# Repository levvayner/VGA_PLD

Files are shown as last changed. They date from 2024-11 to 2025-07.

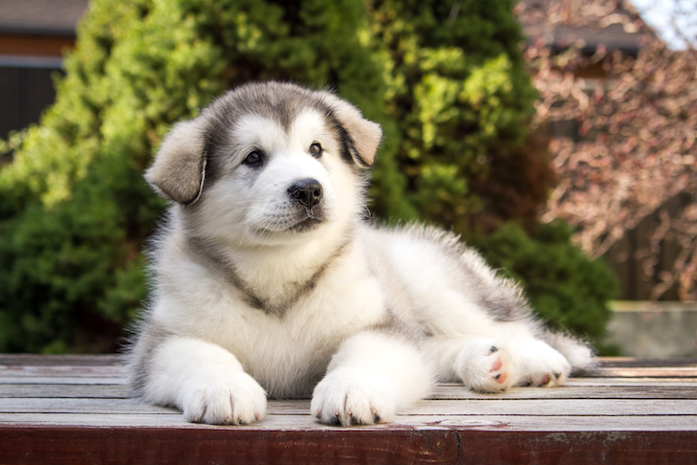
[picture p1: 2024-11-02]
BitmapMapper/puppy_original.png

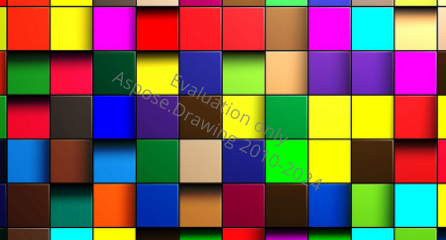
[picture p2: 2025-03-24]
BitmapMapper/blocksResized.bmp

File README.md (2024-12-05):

# VGA Video Card
This project uses TTL components and 2 GALs to create a video card.
There are several parts to the entire development system to aid in development and troubleshooting. Another repository for code that is used on the Arduino Due can be found at https://github.com/levvayner/SRAM-Console

## Parts
 - Hardware Design files in KiCad
 - 2 projects for progamming GAL22V10C PLDs
 - Application used to refine and upload images to the Arduino Due
 - Timing and other documentation
 - Firmware for the Arduino Due to host the video card (https://github.com/levvayner/SRAM-Console)

 ## Getting Started

 ### Prerequisites
 #### Schematics
KiCad software - available for free @ https://www.kicad.org/
 #### Programmable Logic Devices
This can be done with the official Atmel software (https://www.microchip.com/en-us/products/fpgas-and-plds/spld-cplds/pld-design-resources) on windows and using their programmer. 
An alternative approach is to use a cheap progammer like the **TL866+** and using Microsoft Code with the **VS Cupl** extension.
 -http://www.xgecu.com/en/TL866_main.html
-https://marketplace.visualstudio.com/items?itemName=VaynerSystems.VS-Cupl

If choosing the former, follow Atmel's instructions using the included .pld files. If chosing the latter, you can open the workspace and you will see both projects. You can build and deploy the projects right from Code!

You will need to download the Atmel Wincupl progam either way. If you chose to use VS code, you will also need to download and install minipro. More instructions about requirements can be found in the VS Cupl repo https://github.com/levvayner/ATF15xx-cupl

#### Microcontroller
The project uses an Arduino Due uC. The device is low cost, offers a great deal of pins, and has a low price point.

Another device like the Arduino MEGA may suffice. 
Install Microsoft's Code and install the Platform IO extension.
The project can be found here: https://github.com/levvayner/SRAM-Console

## Building the hardware

You can use a breadboard and follow the schematic to build the circuit. First the clock and counters are wired. Then the PLDs are wired to execute combinatory logic to determine timing signals like V-SYNC, H-SYNC, and others like when the screen is not displaying, marking it safe to write to RAM.

The components used in the schematic are available in the KiCad project's output folder.
Currently they are

| Component | Source |
| --- | --- |
| Arduino Due | https://docs.arduino.cc/hardware/due |
| Capactitor (0805) 560 pf  | ebay, mouser, digikey |
| Capacitor Tantalum | ebay, mouser, digikey |
| 2.54mm pins | ebay, mouser, digikey |
| DSUB 15 pin VGA connector | ebay, mouser, digikey |
| USB type A connector | ebay, mouser, digikey |
| Resistors (0805) | ebay, mouser, digikey |
| K6X8008T2B-TF55 | https://www.alldatasheet.com/datasheet-pdf/download/85484/SAMSUNG/K6X8008C2B-TF55.html |
| 74HC245D | ebay, mouser, digikey |
| 74HC161D | ebay, mouser, digikey |
| 74HC32D | ebay, mouser, digikey |
| 74HC08D | ebay, mouser, digikey |
| 74HC00D | ebay, mouser, digikey |
| 74HC14D | ebay, mouser, digikey |
| GAL22V10 | ebay, mouser, digikey |
| 16MHz Full can oscillator | ebay, mouser, digikey |

### GALs
The programmable logic devices are not absolutely required. They can be replaced by inverters and a few logic gates to determine when a counter should trigger a signal (e.g. h-sync at count 603) and use the counter inputs to determine if that number is reached. Several flip flops can be used for storing the state e.g. store v-sync bit at frame 610, clear at 620.
However you may want to change timings or the clock speed to accomplish a different resolution or pixel density. It is much easier to reprogram the GALS to change timing than to re-wire these logic gates. If you have finalized your design, chaning to logic gates and flip flops is recommended. Even better you can use a magnitude comperator instead of a collection of logic gates.

>To progam the gals, you may need to erase the chip. Some chips come locked, and the programmer software from XGECU has an option to clear it. If your changes don't seem to take affect after programming, use their software to make sure the chip is not locked.

There are two projects included. One is used for the horizontal timing, the other for vertical.

>*There is **VGA_SINGLE_PLD** project that can use an **ATF1504AS** instead of these two, but it has not been verified.*

### Arduino 
The project [VGA Controller](https://github.com/levvayner/SRAM-Console) can be used to interface with and develop the video card further. It has functionality to connect to the controller from its serial port, or connect a PS/2 keyboard (experimental) 

## Roadmap
- Add PS/2 mouse support
- Add second SRAM chip to expand data bus to 16 bit
- Add second SRAM chip to round-robin 2 chips between controller and video output, allowing for controller to read/write to SRAM without interfering with the VGA rendering process.

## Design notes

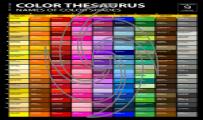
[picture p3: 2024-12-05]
BitmapMapper/colorsResized.bmp

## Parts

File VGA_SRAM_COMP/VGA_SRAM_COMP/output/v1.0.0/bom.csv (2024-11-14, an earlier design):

Reference | Value | Datasheet | Footprint | Qty | DNP
A1 | Arduino_Due_Shield | https://docs.arduino.cc/hardware/due | arduino-library:Arduino_Due_Shield | 1
C1,C2,C3,C4,C5,C7,C8 | 560pf | ~ | Capacitor_SMD:C_0805_2012Metric | 7
C6,C9 | C_Small | ~ | Capacitor_Tantalum_SMD:CP_EIA-7132-28_AVX-C | 2
J1 | DIAG | ~ | Connector_PinSocket_2.54mm:PinSocket_2x04_P2.54mm_Vertical | 1
J2 | PWR AUX | ~ | Connector_PinSocket_2.54mm:PinSocket_2x02_P2.54mm_Vertical | 1
J3 | DE15_Receptacle_HighDensity | ~ | Connector_Dsub:DSUB-15-HD_Female_Horizontal_P2.29x1.98mm_EdgePinOffset8.35mm_Housed_MountingHolesOffset10.89mm | 1
J5 | USB_A | ~ | Connector_USB:USB_A_Molex_67643_Horizontal | 1
R1,R4,R7 | R470 | ~ | Resistor_SMD:R_0805_2012Metric | 3
R2,R5,R8 | R900 | ~ | Resistor_SMD:R_0805_2012Metric | 3
R3,R6 | R1.5K | ~ | Resistor_SMD:R_0805_2012Metric | 2
R10 | R10K | ~ | Resistor_SMD:R_0805_2012Metric | 1
R11,R12 | R100 | ~ | Resistor_SMD:R_0805_2012Metric | 2
U1 | K6X8008T2B-TF55 | https://www.alldatasheet.com/datasheet-pdf/download/85484/SAMSUNG/K6X8008C2B-TF55.html | Package_SO:TSOP-II-44_10.16x18.41mm_P0.8mm | 1
U2,U11,U12,U13,U14,U18,U20 | 74HC245 | http://www.ti.com/lit/gpn/sn74HC245 | Package_SO:SOP-20_7.5x12.8mm_P1.27mm | 7
U3,U4,U5,U6,U7,U10 | 74LS161 | http://www.ti.com/lit/gpn/sn74LS161 | Package_SO:SO-16_3.9x9.9mm_P1.27mm | 6
U8,U9 | GAL22V10 |  | Package_DIP:DIP-24_W10.16mm_Socket | 2
U15 | 74LS32 | http://www.ti.com/lit/gpn/sn74LS32 | Package_SO:SO-14_3.9x8.65mm_P1.27mm | 1
U16 | 74LS08 | http://www.ti.com/lit/gpn/sn74LS08 | Package_SO:SO-14_3.9x8.65mm_P1.27mm | 1
U17 | 74HC00 | http://www.ti.com/lit/gpn/sn74hc00 | Package_SO:SO-14_3.9x8.65mm_P1.27mm | 1
U19 | 74HC14 | http://www.ti.com/lit/gpn/sn74HC14 | Package_SO:SO-14_3.9x8.65mm_P1.27mm | 1
X1 | TCXO-14 | http://www.golledge.com/pdf/products/tcxos/gtxos14.pdf | Oscillator:Oscillator_DIP-14 | 1

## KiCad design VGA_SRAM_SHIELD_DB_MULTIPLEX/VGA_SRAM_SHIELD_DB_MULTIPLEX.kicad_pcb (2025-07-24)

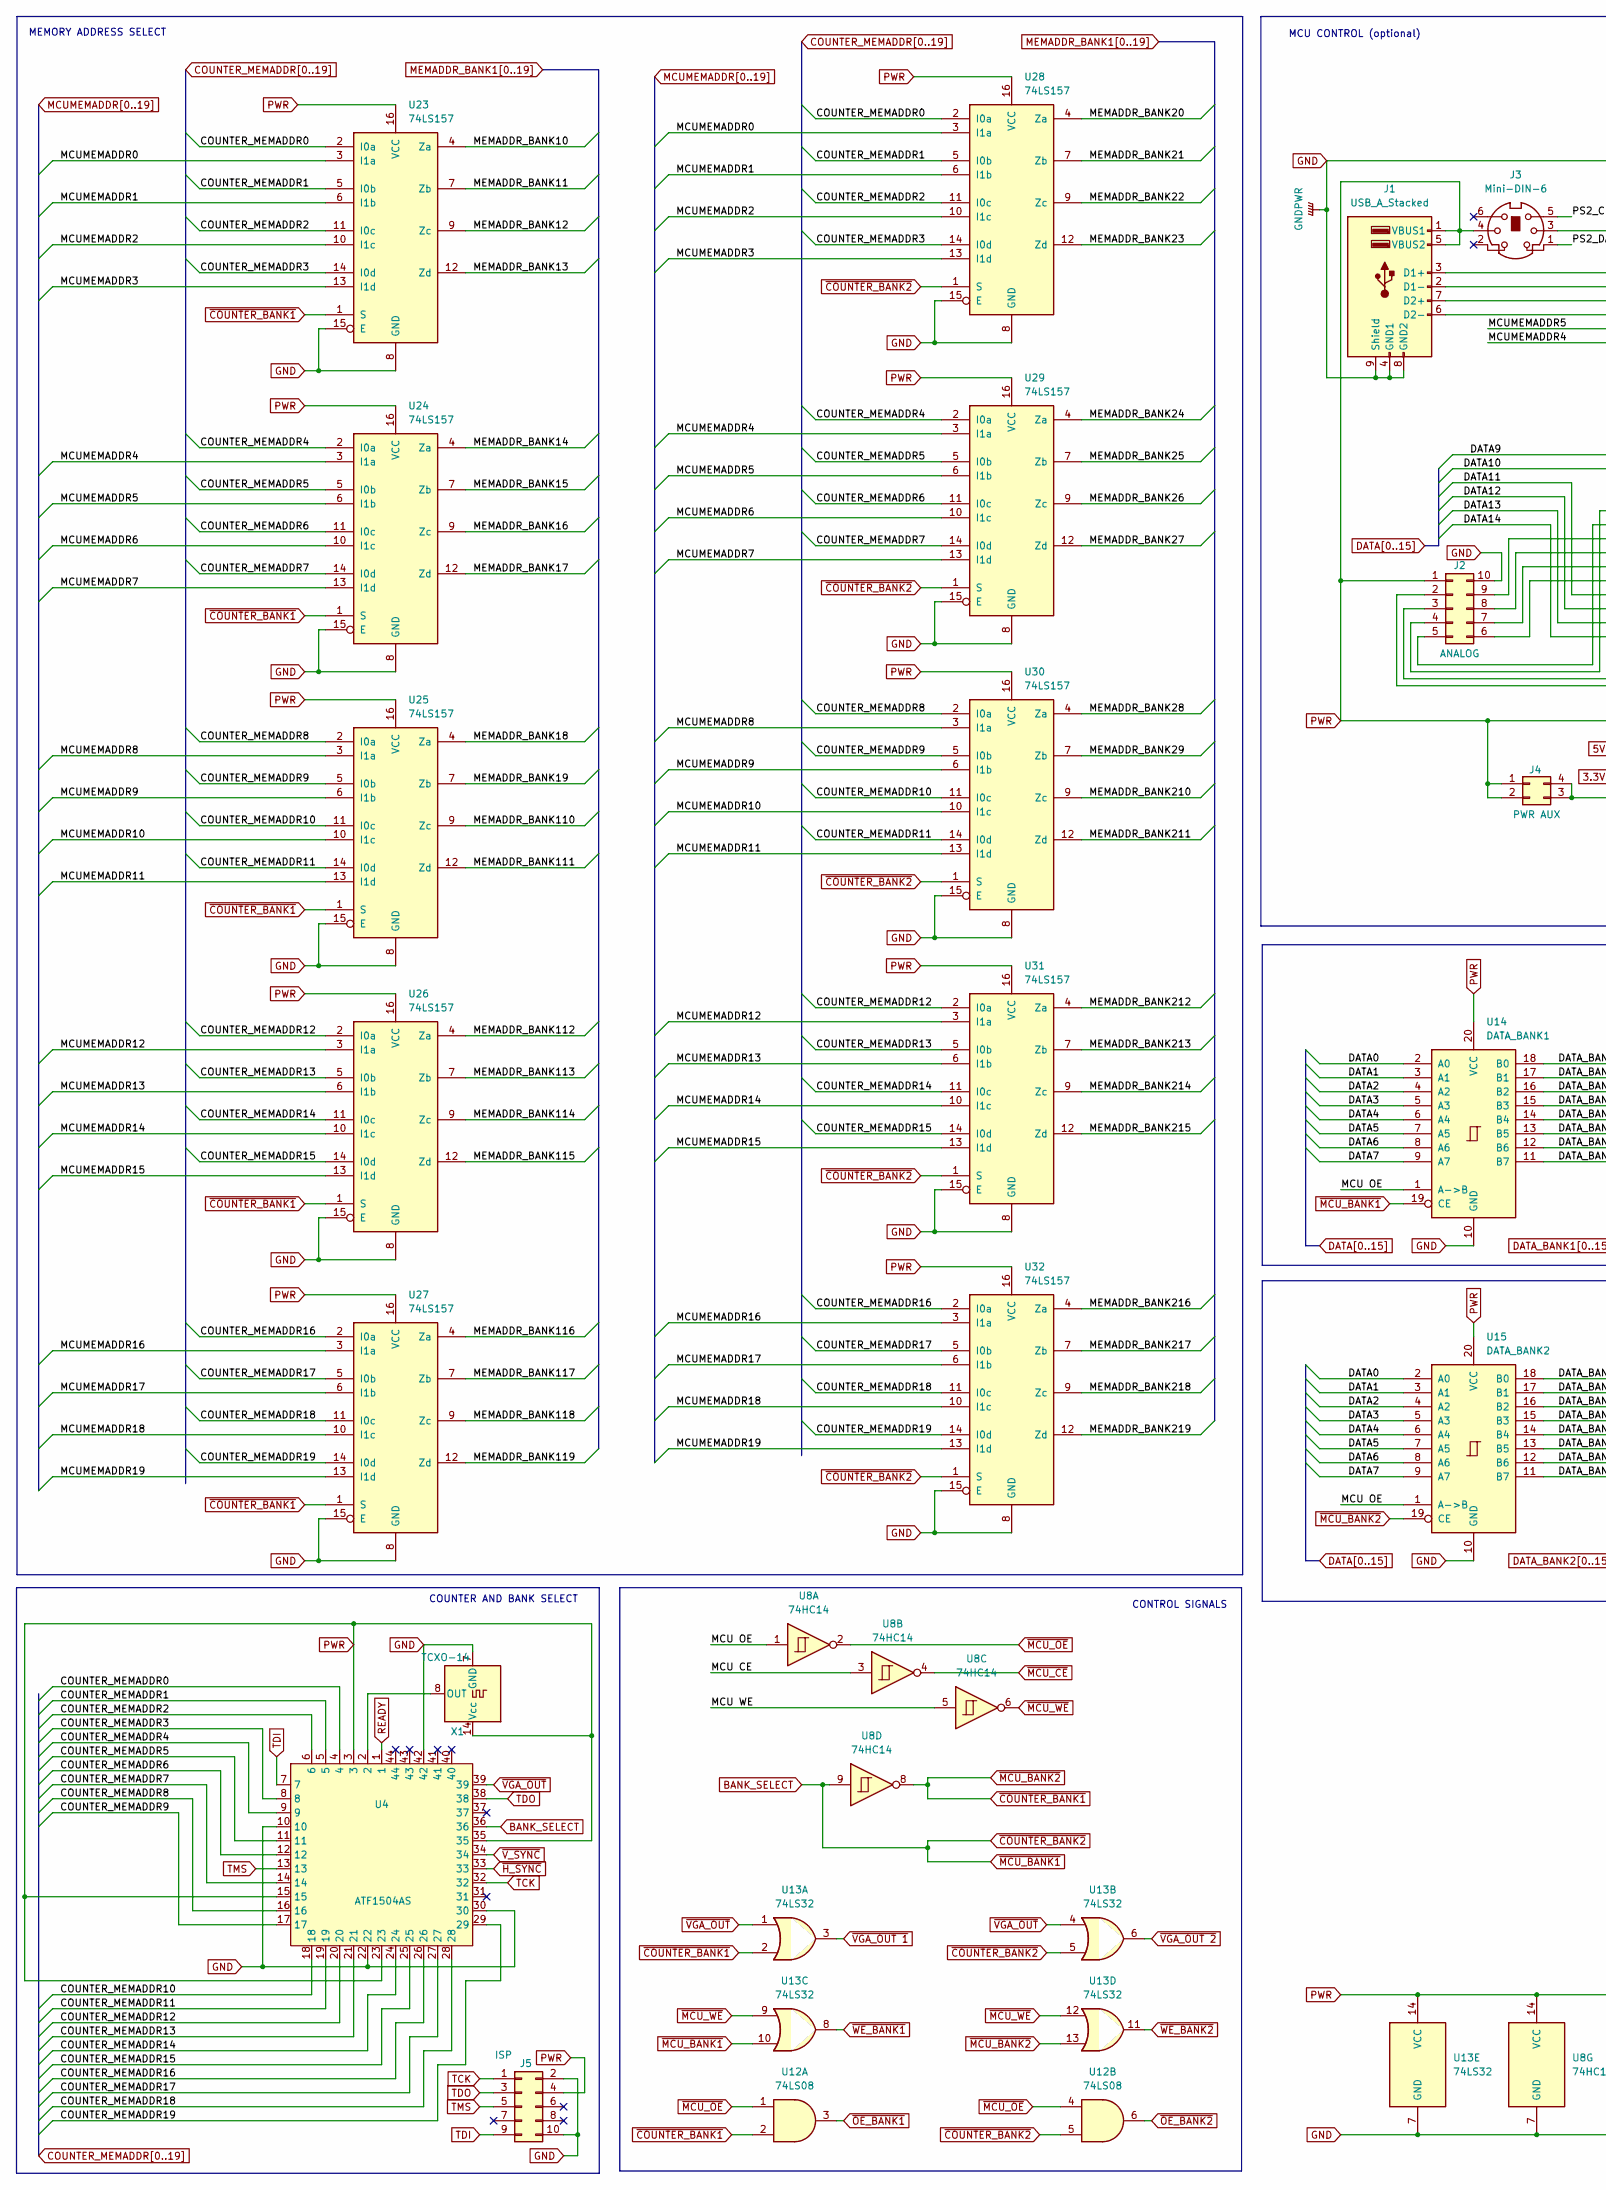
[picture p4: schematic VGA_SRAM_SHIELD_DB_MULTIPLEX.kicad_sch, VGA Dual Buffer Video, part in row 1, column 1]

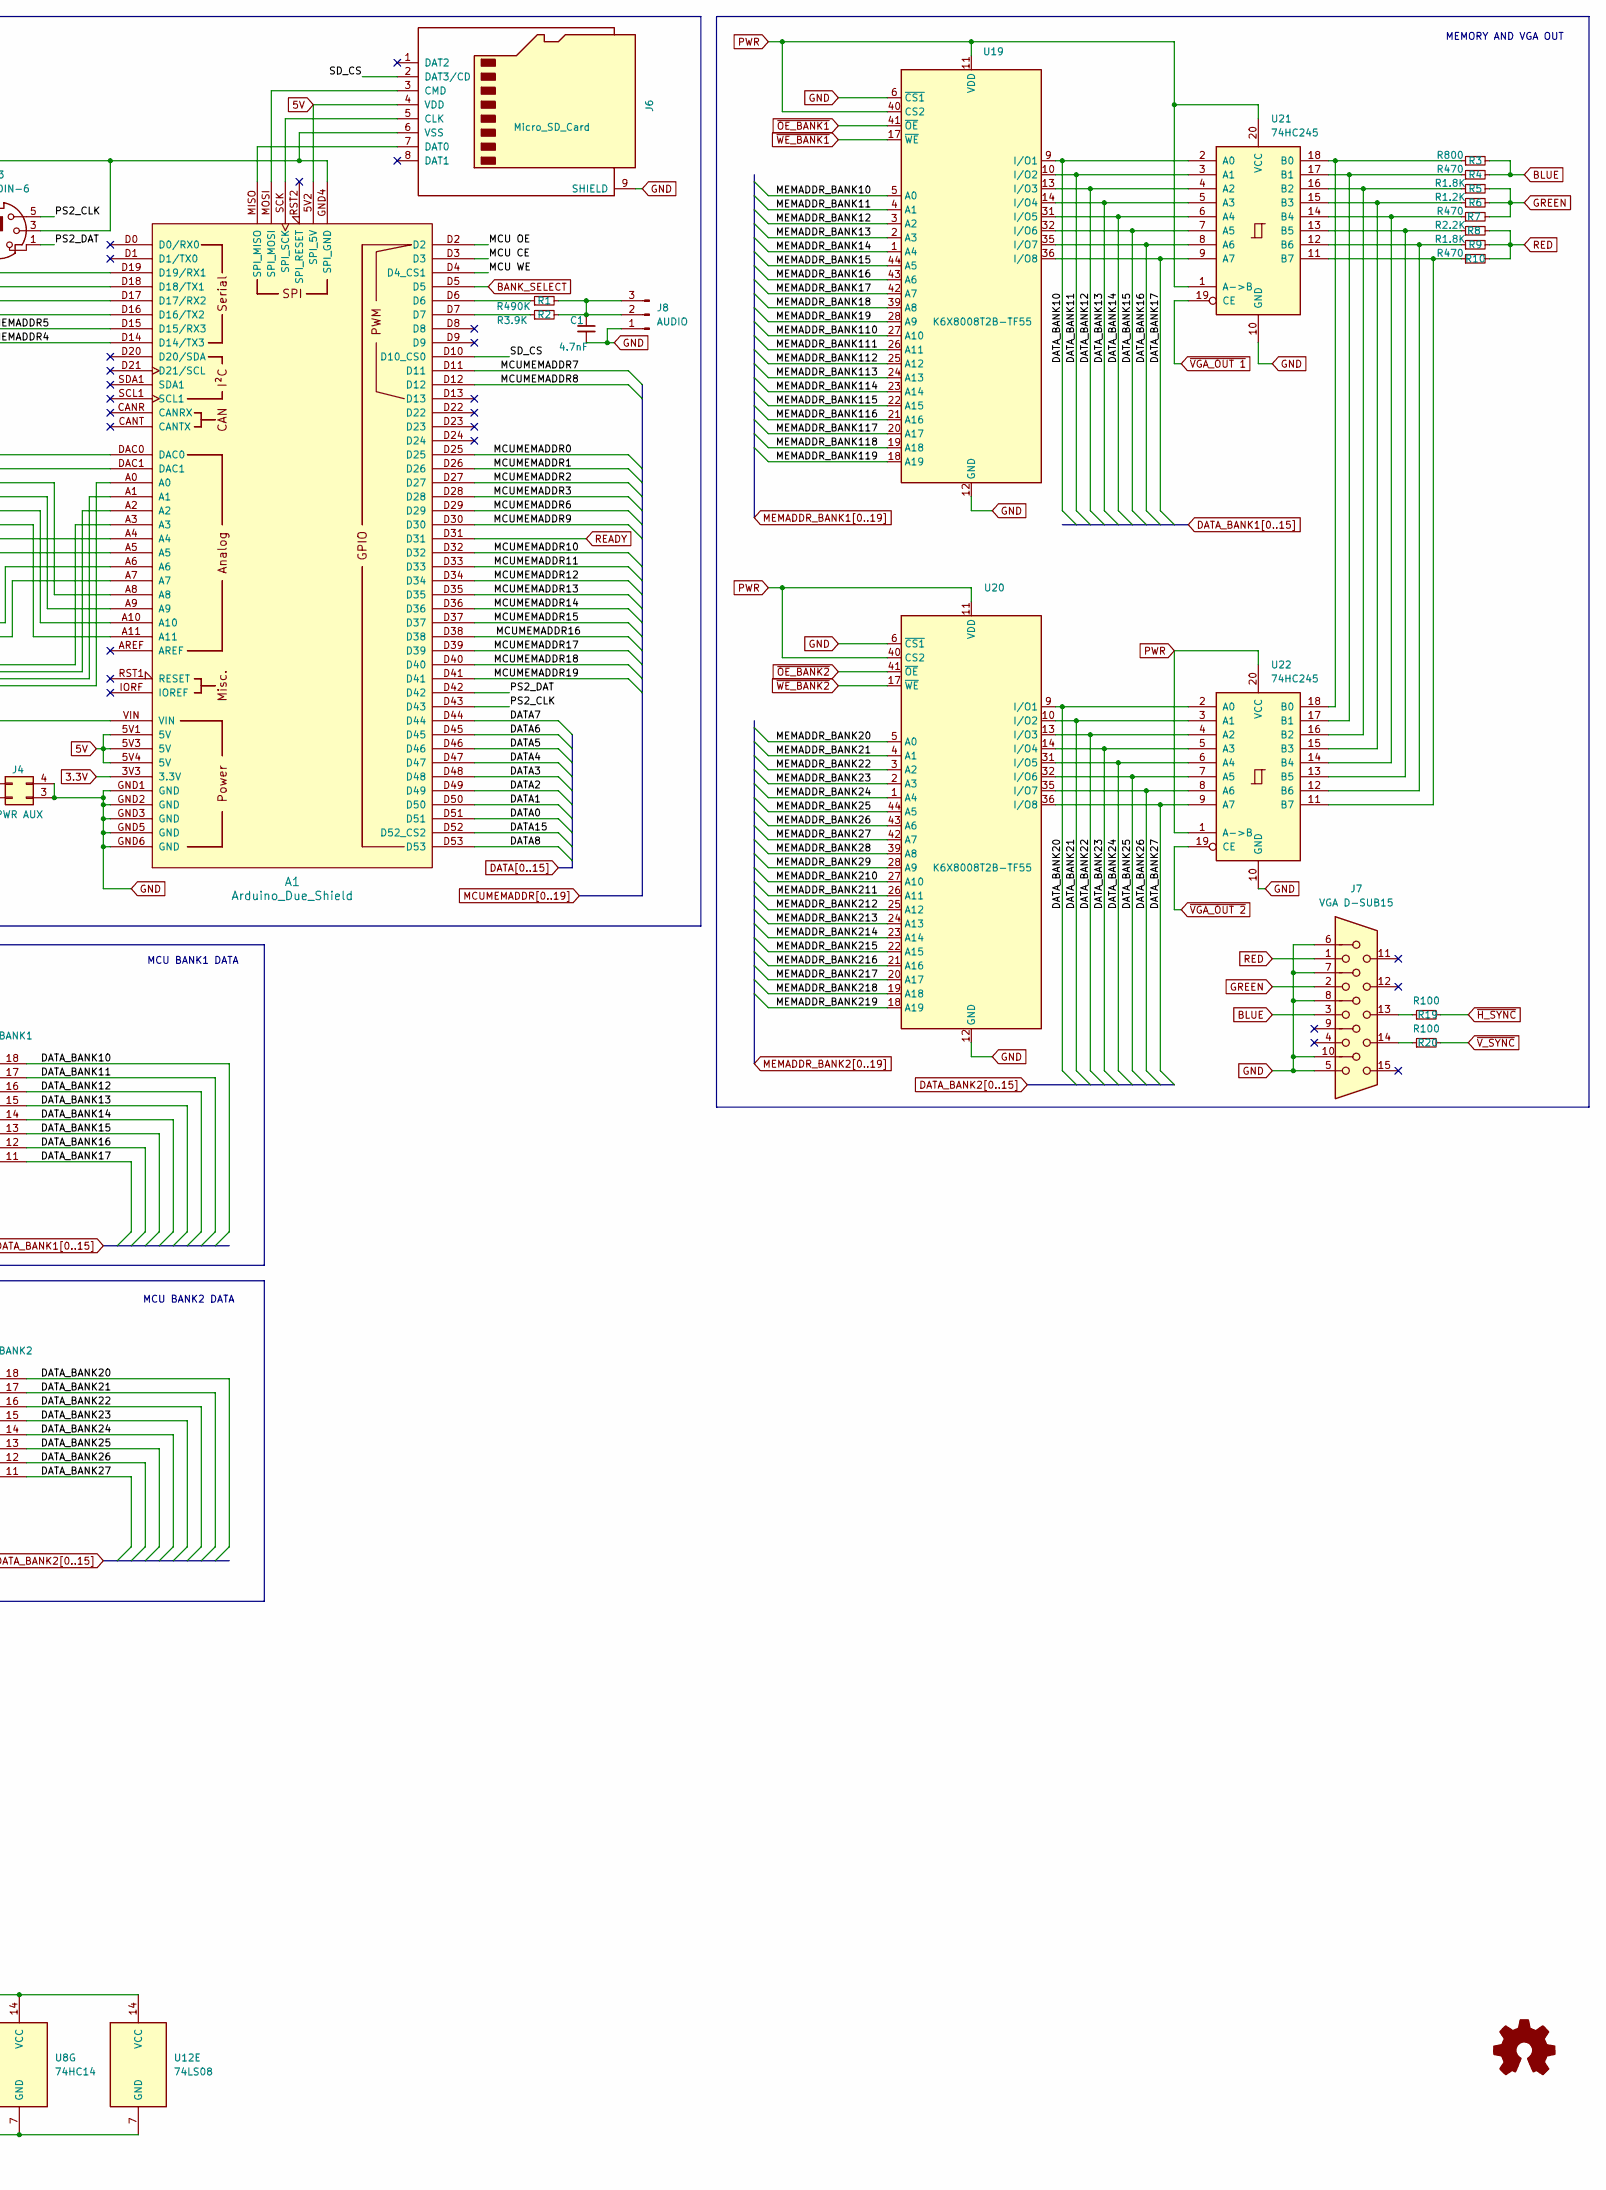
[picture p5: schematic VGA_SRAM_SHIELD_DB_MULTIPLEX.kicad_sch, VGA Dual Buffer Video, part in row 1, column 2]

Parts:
A1: Arduino_Due_Shield
C1: 4.7nF; C_0805_2012Metric
J1: USB_A_Stacked; USB_A_CUI_UJ2-ADH-TH_Horizontal_Stacked
J2: ANALOG; PinSocket_2x05_P2.54mm_Vertical
J3: Mini-DIN-6; mini-DIN 6
J4: PWR AUX; PinSocket_2x02_P2.54mm_Vertical
J5: ISP; PinSocket_2x05_P2.54mm_Vertical
J6: Micro_SD_Card; J_SD_Card-micro_socket_A
J7: VGA D-SUB15; DSUB-15-HD_Female_Horizontal_P2.29x1.98mm_EdgePinOffset8.35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
J8: AUDIO; PinSocket_1x03_P2.54mm_Vertical
R1: R490K; R_0805_2012Metric
R2: R3.9K; R_0805_2012Metric
R3: R800; R_0805_2012Metric
R4, R7, R10: R470; R_0805_2012Metric
R5, R9: R1.8K; R_0805_2012Metric
R6: R1.2K; R_0805_2012Metric
R8: R2.2K; R_0805_2012Metric
R19, R20: R100; R_0805_2012Metric
U4: ATF1504AS; PLCC-44_THT-Socket
U8: 74HC14; SO-14_3.9x8.65mm_P1.27mm
U12: 74LS08; SO-14_3.9x8.65mm_P1.27mm
U13: 74LS32; SO-14_3.9x8.65mm_P1.27mm
U14: DATA_BANK1; SOP-20_7.5x12.8mm_P1.27mm
U15: DATA_BANK2; SOP-20_7.5x12.8mm_P1.27mm
U19, U20: K6X8008T2B-TF55; TSOP-II-44_10.16x18.41mm_P0.8mm
U21, U22: 74HC245; SOP-20_7.5x12.8mm_P1.27mm
U23, U24, U25, U26, U27, U28, U29, U30, U31, U32: 74LS157; SOP-16_3.9x9.9mm_P1.27mm
X1: TCXO-14; Oscillator_DIP-14

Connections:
3.3V: A1.3V3 (3.3V)
5V: A1.5V1 (5V), A1.5V2 (SPI_5V), A1.5V3 (5V), A1.5V4 (5V), J6.4 (VDD)
/MCU CE: A1.D3, U8.3
/MCU OE: A1.D2, U8.1, U14.1 (A->B), U15.1 (A->B)
/MCU WE: A1.D4 (D4_CS1), U8.5
/PS2_CLK: A1.D43, J3.5
/PS2_DAT: A1.D42, J3.1
/SD_CS: A1.D10 (D10_CS0), J6.2 (DAT3/CD)
BANK_SELECT: A1.D5, U4.36, U8.9, U12.5, U13.5, U13.10, U14.19 (CE), U28.1 (S), U29.1 (S), U30.1 (S), U31.1 (S), U32.1 (S)
BLUE: J7.3, R3.2, R4.2
COUNTER_MEMADDR0: U4.4, U23.2 (I0a), U28.2 (I0a)
COUNTER_MEMADDR1: U4.5, U23.5 (I0b), U28.5 (I0b)
COUNTER_MEMADDR2: U4.6, U23.11 (I0c), U28.11 (I0c)
COUNTER_MEMADDR3: U4.8, U23.14 (I0d), U28.14 (I0d)
COUNTER_MEMADDR4: U4.9, U24.2 (I0a), U29.2 (I0a)
COUNTER_MEMADDR5: U4.11, U24.5 (I0b), U29.5 (I0b)
COUNTER_MEMADDR6: U4.12, U24.11 (I0c), U29.11 (I0c)
COUNTER_MEMADDR7: U4.14, U24.14 (I0d), U29.14 (I0d)
COUNTER_MEMADDR8: U4.16, U25.2 (I0a), U30.2 (I0a)
COUNTER_MEMADDR9: U4.17, U25.5 (I0b), U30.5 (I0b)
COUNTER_MEMADDR10: U4.18, U25.11 (I0c), U30.11 (I0c)
COUNTER_MEMADDR11: U4.19, U25.14 (I0d), U30.14 (I0d)
COUNTER_MEMADDR12: U4.20, U26.2 (I0a), U31.2 (I0a)
COUNTER_MEMADDR13: U4.21, U26.5 (I0b), U31.5 (I0b)
COUNTER_MEMADDR14: U4.24, U26.11 (I0c), U31.11 (I0c)
COUNTER_MEMADDR15: U4.25, U26.14 (I0d), U31.14 (I0d)
COUNTER_MEMADDR16: U4.26, U27.2 (I0a), U32.2 (I0a)
COUNTER_MEMADDR17: U4.27, U27.5 (I0b), U32.5 (I0b)
COUNTER_MEMADDR18: U4.28, U27.11 (I0c), U32.11 (I0c)
COUNTER_MEMADDR19: U4.29, U27.14 (I0d), U32.14 (I0d)
DATA0: A1.D51, U14.2 (A0), U15.2 (A0)
DATA1: A1.D50, U14.3 (A1), U15.3 (A1)
DATA2: A1.D49, U14.4 (A2), U15.4 (A2)
DATA3: A1.D48, U14.5 (A3), U15.5 (A3)
DATA4: A1.D47, U14.6 (A4), U15.6 (A4)
DATA5: A1.D46, U14.7 (A5), U15.7 (A5)
DATA6: A1.D45, U14.8 (A6), U15.8 (A6)
DATA7: A1.D44, U14.9 (A7), U15.9 (A7)
DATA8: A1.D53
DATA9: A1.DAC0
DATA10: A1.DAC1
DATA11: A1.A8
DATA12: A1.A9
DATA13: A1.A10
DATA14: A1.A11
DATA15: A1.D52 (D52_CS2)
DATA_BANK10: U14.18 (B0), U19.9 (I/O1), U21.2 (A0)
DATA_BANK11: U14.17 (B1), U19.10 (I/O2), U21.3 (A1)
DATA_BANK12: U14.16 (B2), U19.13 (I/O3), U21.4 (A2)
DATA_BANK13: U14.15 (B3), U19.14 (I/O4), U21.5 (A3)
DATA_BANK14: U14.14 (B4), U19.31 (I/O5), U21.6 (A4)
DATA_BANK15: U14.13 (B5), U19.32 (I/O6), U21.7 (A5)
DATA_BANK16: U14.12 (B6), U19.35 (I/O7), U21.8 (A6)
DATA_BANK17: U14.11 (B7), U19.36 (I/O8), U21.9 (A7)
DATA_BANK20: U15.18 (B0), U20.9 (I/O1), U22.2 (A0)
DATA_BANK21: U15.17 (B1), U20.10 (I/O2), U22.3 (A1)
DATA_BANK22: U15.16 (B2), U20.13 (I/O3), U22.4 (A2)
DATA_BANK23: U15.15 (B3), U20.14 (I/O4), U22.5 (A3)
DATA_BANK24: U15.14 (B4), U20.31 (I/O5), U22.6 (A4)
DATA_BANK25: U15.13 (B5), U20.32 (I/O6), U22.7 (A5)
DATA_BANK26: U15.12 (B6), U20.35 (I/O7), U22.8 (A6)
DATA_BANK27: U15.11 (B7), U20.36 (I/O8), U22.9 (A7)
GND: A1.GND1 (GND), A1.GND2 (GND), A1.GND3 (GND), A1.GND4 (SPI_GND), A1.GND5 (GND), A1.GND6 (GND), C1.2, J1.4 (GND1), J1.8 (GND2), J1.9 (Shield), J2.10, J3.3, J4.3, J4.4, J5.2, J5.10, J6.6 (VSS), J6.9 (SHIELD), J7.5, J7.6, J7.7, J7.8, J7.10, J8.1, U4.10, U4.22, U4.30, U4.42, U8.7 (GND), U12.7 (GND), U13.7 (GND), U14.10 (GND), U15.10 (GND), U19.6 (~CS1), U19.12 (GND), U19.34 (GND), U20.6 (~CS1), U20.12 (GND), U20.34 (GND), U21.10 (GND), U22.10 (GND), U23.8 (GND), U23.15 (E), U24.8 (GND), U24.15 (E), U25.8 (GND), U25.15 (E), U26.8 (GND), U26.15 (E), U27.8 (GND), U27.15 (E), U28.8 (GND), U28.15 (E), U29.8 (GND), U29.15 (E), U30.8 (GND), U30.15 (E), U31.8 (GND), U31.15 (E), U32.8 (GND), U32.15 (E), X1.7 (GND)
GREEN: J7.2, R5.2, R6.2, R7.2
MCUMEMADDR0: A1.D25, U23.3 (I1a), U28.3 (I1a)
MCUMEMADDR1: A1.D26, U23.6 (I1b), U28.6 (I1b)
MCUMEMADDR2: A1.D27, U23.10 (I1c), U28.10 (I1c)
MCUMEMADDR3: A1.D28, U23.13 (I1d), U28.13 (I1d)
MCUMEMADDR4: A1.D14 (D14/TX3), U24.3 (I1a), U29.3 (I1a)
MCUMEMADDR5: A1.D15 (D15/RX3), U24.6 (I1b), U29.6 (I1b)
MCUMEMADDR6: A1.D29, U24.10 (I1c), U29.10 (I1c)
MCUMEMADDR7: A1.D11, U24.13 (I1d), U29.13 (I1d)
MCUMEMADDR8: A1.D12, U25.3 (I1a), U30.3 (I1a)
MCUMEMADDR9: A1.D30, U25.6 (I1b), U30.6 (I1b)
MCUMEMADDR10: A1.D32, U25.10 (I1c), U30.10 (I1c)
MCUMEMADDR11: A1.D33, U25.13 (I1d), U30.13 (I1d)
MCUMEMADDR12: A1.D34, U26.3 (I1a), U31.3 (I1a)
MCUMEMADDR13: A1.D35, U26.6 (I1b), U31.6 (I1b)
MCUMEMADDR14: A1.D36, U26.10 (I1c), U31.10 (I1c)
MCUMEMADDR15: A1.D37, U26.13 (I1d), U31.13 (I1d)
MCUMEMADDR16: A1.D38, U27.3 (I1a), U32.3 (I1a)
MCUMEMADDR17: A1.D39, U27.6 (I1b), U32.6 (I1b)
MCUMEMADDR18: A1.D40, U27.10 (I1c), U32.10 (I1c)
MCUMEMADDR19: A1.D41, U27.13 (I1d), U32.13 (I1d)
MEMADDR_BANK10: U19.5 (A0), U23.4 (Za)
MEMADDR_BANK11: U19.4 (A1), U23.7 (Zb)
MEMADDR_BANK12: U19.3 (A2), U23.9 (Zc)
MEMADDR_BANK13: U19.2 (A3), U23.12 (Zd)
MEMADDR_BANK14: U19.1 (A4), U24.4 (Za)
MEMADDR_BANK15: U19.44 (A5), U24.7 (Zb)
MEMADDR_BANK16: U19.43 (A6), U24.9 (Zc)
MEMADDR_BANK17: U19.42 (A7), U24.12 (Zd)
MEMADDR_BANK18: U19.39 (A8), U25.4 (Za)
MEMADDR_BANK19: U19.28 (A9), U25.7 (Zb)
MEMADDR_BANK20: U20.5 (A0), U28.4 (Za)
MEMADDR_BANK21: U20.4 (A1), U28.7 (Zb)
MEMADDR_BANK22: U20.3 (A2), U28.9 (Zc)
MEMADDR_BANK23: U20.2 (A3), U28.12 (Zd)
MEMADDR_BANK24: U20.1 (A4), U29.4 (Za)
MEMADDR_BANK25: U20.44 (A5), U29.7 (Zb)
MEMADDR_BANK26: U20.43 (A6), U29.9 (Zc)
MEMADDR_BANK27: U20.42 (A7), U29.12 (Zd)
MEMADDR_BANK28: U20.39 (A8), U30.4 (Za)
MEMADDR_BANK29: U20.28 (A9), U30.7 (Zb)
MEMADDR_BANK110: U19.27 (A10), U25.9 (Zc)
MEMADDR_BANK111: U19.26 (A11), U25.12 (Zd)
MEMADDR_BANK112: U19.25 (A12), U26.4 (Za)
MEMADDR_BANK113: U19.24 (A13), U26.7 (Zb)
MEMADDR_BANK114: U19.23 (A14), U26.9 (Zc)
MEMADDR_BANK115: U19.22 (A15), U26.12 (Zd)
MEMADDR_BANK116: U19.21 (A16), U27.4 (Za)
MEMADDR_BANK117: U19.20 (A17), U27.7 (Zb)
MEMADDR_BANK118: U19.19 (A18), U27.9 (Zc)
MEMADDR_BANK119: U19.18 (A19), U27.12 (Zd)
MEMADDR_BANK210: U20.27 (A10), U30.9 (Zc)
MEMADDR_BANK211: U20.26 (A11), U30.12 (Zd)
MEMADDR_BANK212: U20.25 (A12), U31.4 (Za)
MEMADDR_BANK213: U20.24 (A13), U31.7 (Zb)
MEMADDR_BANK214: U20.23 (A14), U31.9 (Zc)
MEMADDR_BANK215: U20.22 (A15), U31.12 (Zd)
MEMADDR_BANK216: U20.21 (A16), U32.4 (Za)
MEMADDR_BANK217: U20.20 (A17), U32.7 (Zb)
MEMADDR_BANK218: U20.19 (A18), U32.9 (Zc)
MEMADDR_BANK219: U20.18 (A19), U32.12 (Zd)
unnamed: A1.D16 (D16/TX2), J1.6 (D2-)
unnamed: A1.D17 (D17/RX2), J1.7 (D2+)
unnamed: A1.D18 (D18/TX1), J1.2 (D1-)
unnamed: A1.D19 (D19/RX1), J1.3 (D1+)
unnamed: A1.D6, R1.1
unnamed: A1.D7, R2.1
unnamed: A1.MISO (SPI_MISO), J6.7 (DAT0)
unnamed: A1.MOSI (SPI_MOSI), J6.3 (CMD)
unnamed: A1.SCK (SPI_SCK), J6.5 (CLK)
unnamed: A1.A0, J2.2
unnamed: A1.A1, J2.3
unnamed: A1.A2, J2.4
unnamed: A1.A3, J2.5
unnamed: A1.A7, J2.6
unnamed: A1.A6, J2.7
unnamed: A1.A5, J2.8
unnamed: A1.A4, J2.9
unnamed: J7.13, R19.1
unnamed: J7.14, R20.1
unnamed: C1.1, J8.2, J8.3, R1.2, R2.2
unnamed: R3.1, U21.18 (B0), U22.18 (B0)
unnamed: R4.1, U21.17 (B1), U22.17 (B1)
unnamed: R5.1, U21.16 (B2), U22.16 (B2)
unnamed: R6.1, U21.15 (B3), U22.15 (B3)
unnamed: R7.1, U21.14 (B4), U22.14 (B4)
unnamed: R8.1, U21.13 (B5), U22.13 (B5)
unnamed: R9.1, U21.12 (B6), U22.12 (B6)
unnamed: R10.1, U21.11 (B7), U22.11 (B7)
unnamed: U4.2, X1.8 (OUT)
PWR: A1.VIN, J1.1 (VBUS1), J1.5 (VBUS2), J2.1, J3.4, J4.1, J4.2, J5.4, U4.3, U4.15, U4.23, U4.35, U8.14 (VCC), U12.14 (VCC), U13.14 (VCC), U14.20 (VCC), U15.20 (VCC), U19.11 (VDD), U19.33 (VDD), U19.40 (CS2), U20.11 (VDD), U20.33 (VDD), U20.40 (CS2), U21.1 (A->B), U21.20 (VCC), U22.1 (A->B), U22.20 (VCC), U23.16 (VCC), U24.16 (VCC), U25.16 (VCC), U26.16 (VCC), U27.16 (VCC), U28.16 (VCC), U29.16 (VCC), U30.16 (VCC), U31.16 (VCC), U32.16 (VCC), X1.14 (Vcc)
READY: A1.D31, U4.1
RED: J7.1, R8.2, R9.2, R10.2
TCK: J5.1, U4.32
TDI: J5.9, U4.7
TDO: J5.3, U4.38
TMS: J5.5, U4.13
~COUNTER_BANK1: U8.8, U12.2, U13.2, U13.13, U15.19 (CE), U23.1 (S), U24.1 (S), U25.1 (S), U26.1 (S), U27.1 (S)
~H_SYNC: R19.2, U4.33
~MCU_CE: U8.4
~MCU_OE: U8.2, U12.1, U12.4
~MCU_WE: U8.6, U13.9, U13.12
~OE_BANK1: U12.3, U19.41 (~OE)
~OE_BANK2: U12.6, U20.41 (~OE)
~VGA_OUT 1: U13.3, U21.19 (CE)
~VGA_OUT 2: U13.6, U22.19 (CE)
~VGA_OUT: U4.39, U13.1, U13.4
~V_SYNC: R20.2, U4.34
~WE_BANK1: U13.8, U19.17 (~WE)
~WE_BANK2: U13.11, U20.17 (~WE)

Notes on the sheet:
MEMORY ADDRESS SELECT
MCU BANK1 DATA
MEMORY AND VGA OUT
MCU BANK2 DATA
MCU CONTROL (optional)
COUNTER AND BANK SELECT
CONTROL SIGNALS

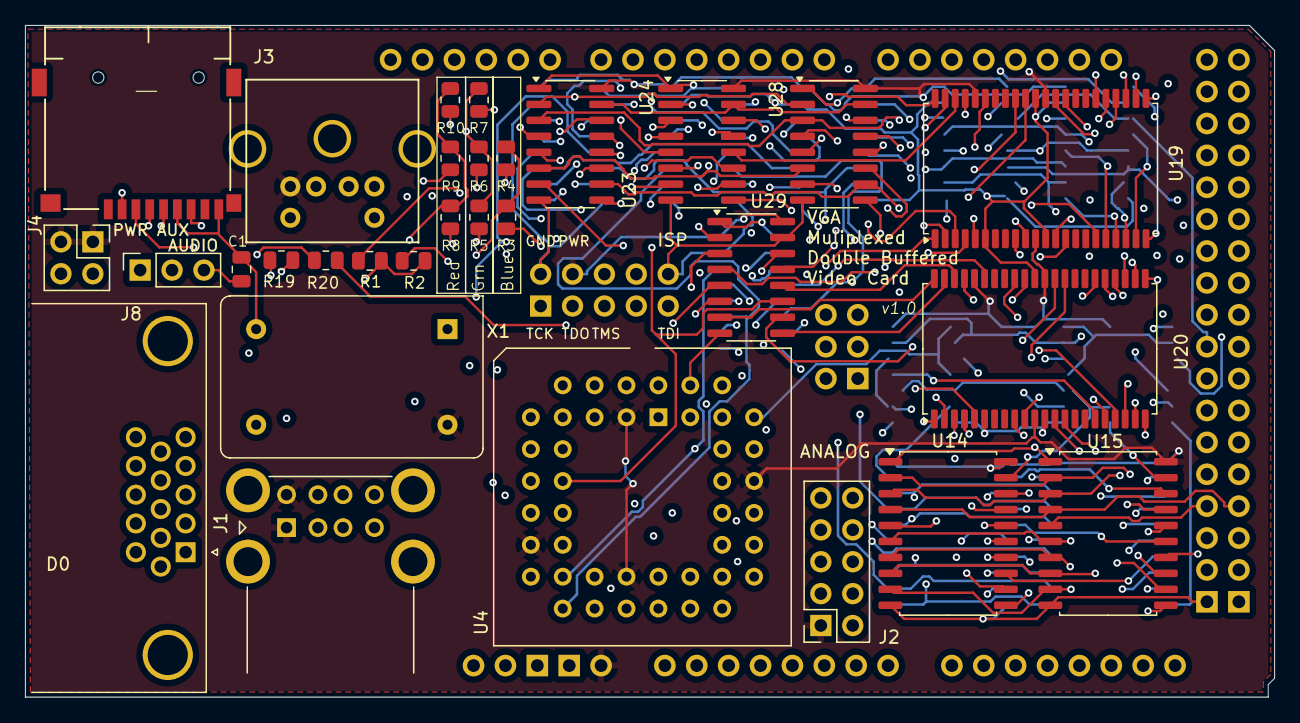
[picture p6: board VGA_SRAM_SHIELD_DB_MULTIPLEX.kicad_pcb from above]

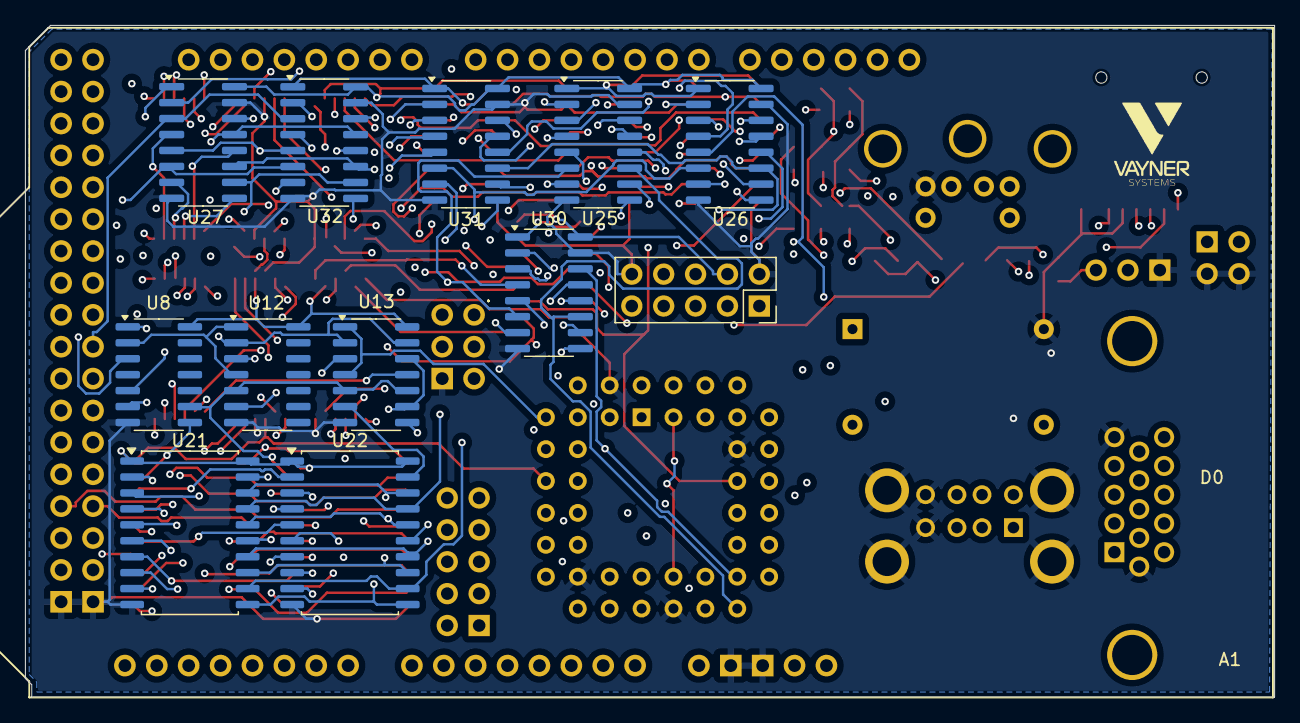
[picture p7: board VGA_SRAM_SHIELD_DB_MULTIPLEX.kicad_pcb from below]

Board: 6 copper layers, 99.5 x 53.5 mm, 43 parts (12 on the bottom side), 163 nets.

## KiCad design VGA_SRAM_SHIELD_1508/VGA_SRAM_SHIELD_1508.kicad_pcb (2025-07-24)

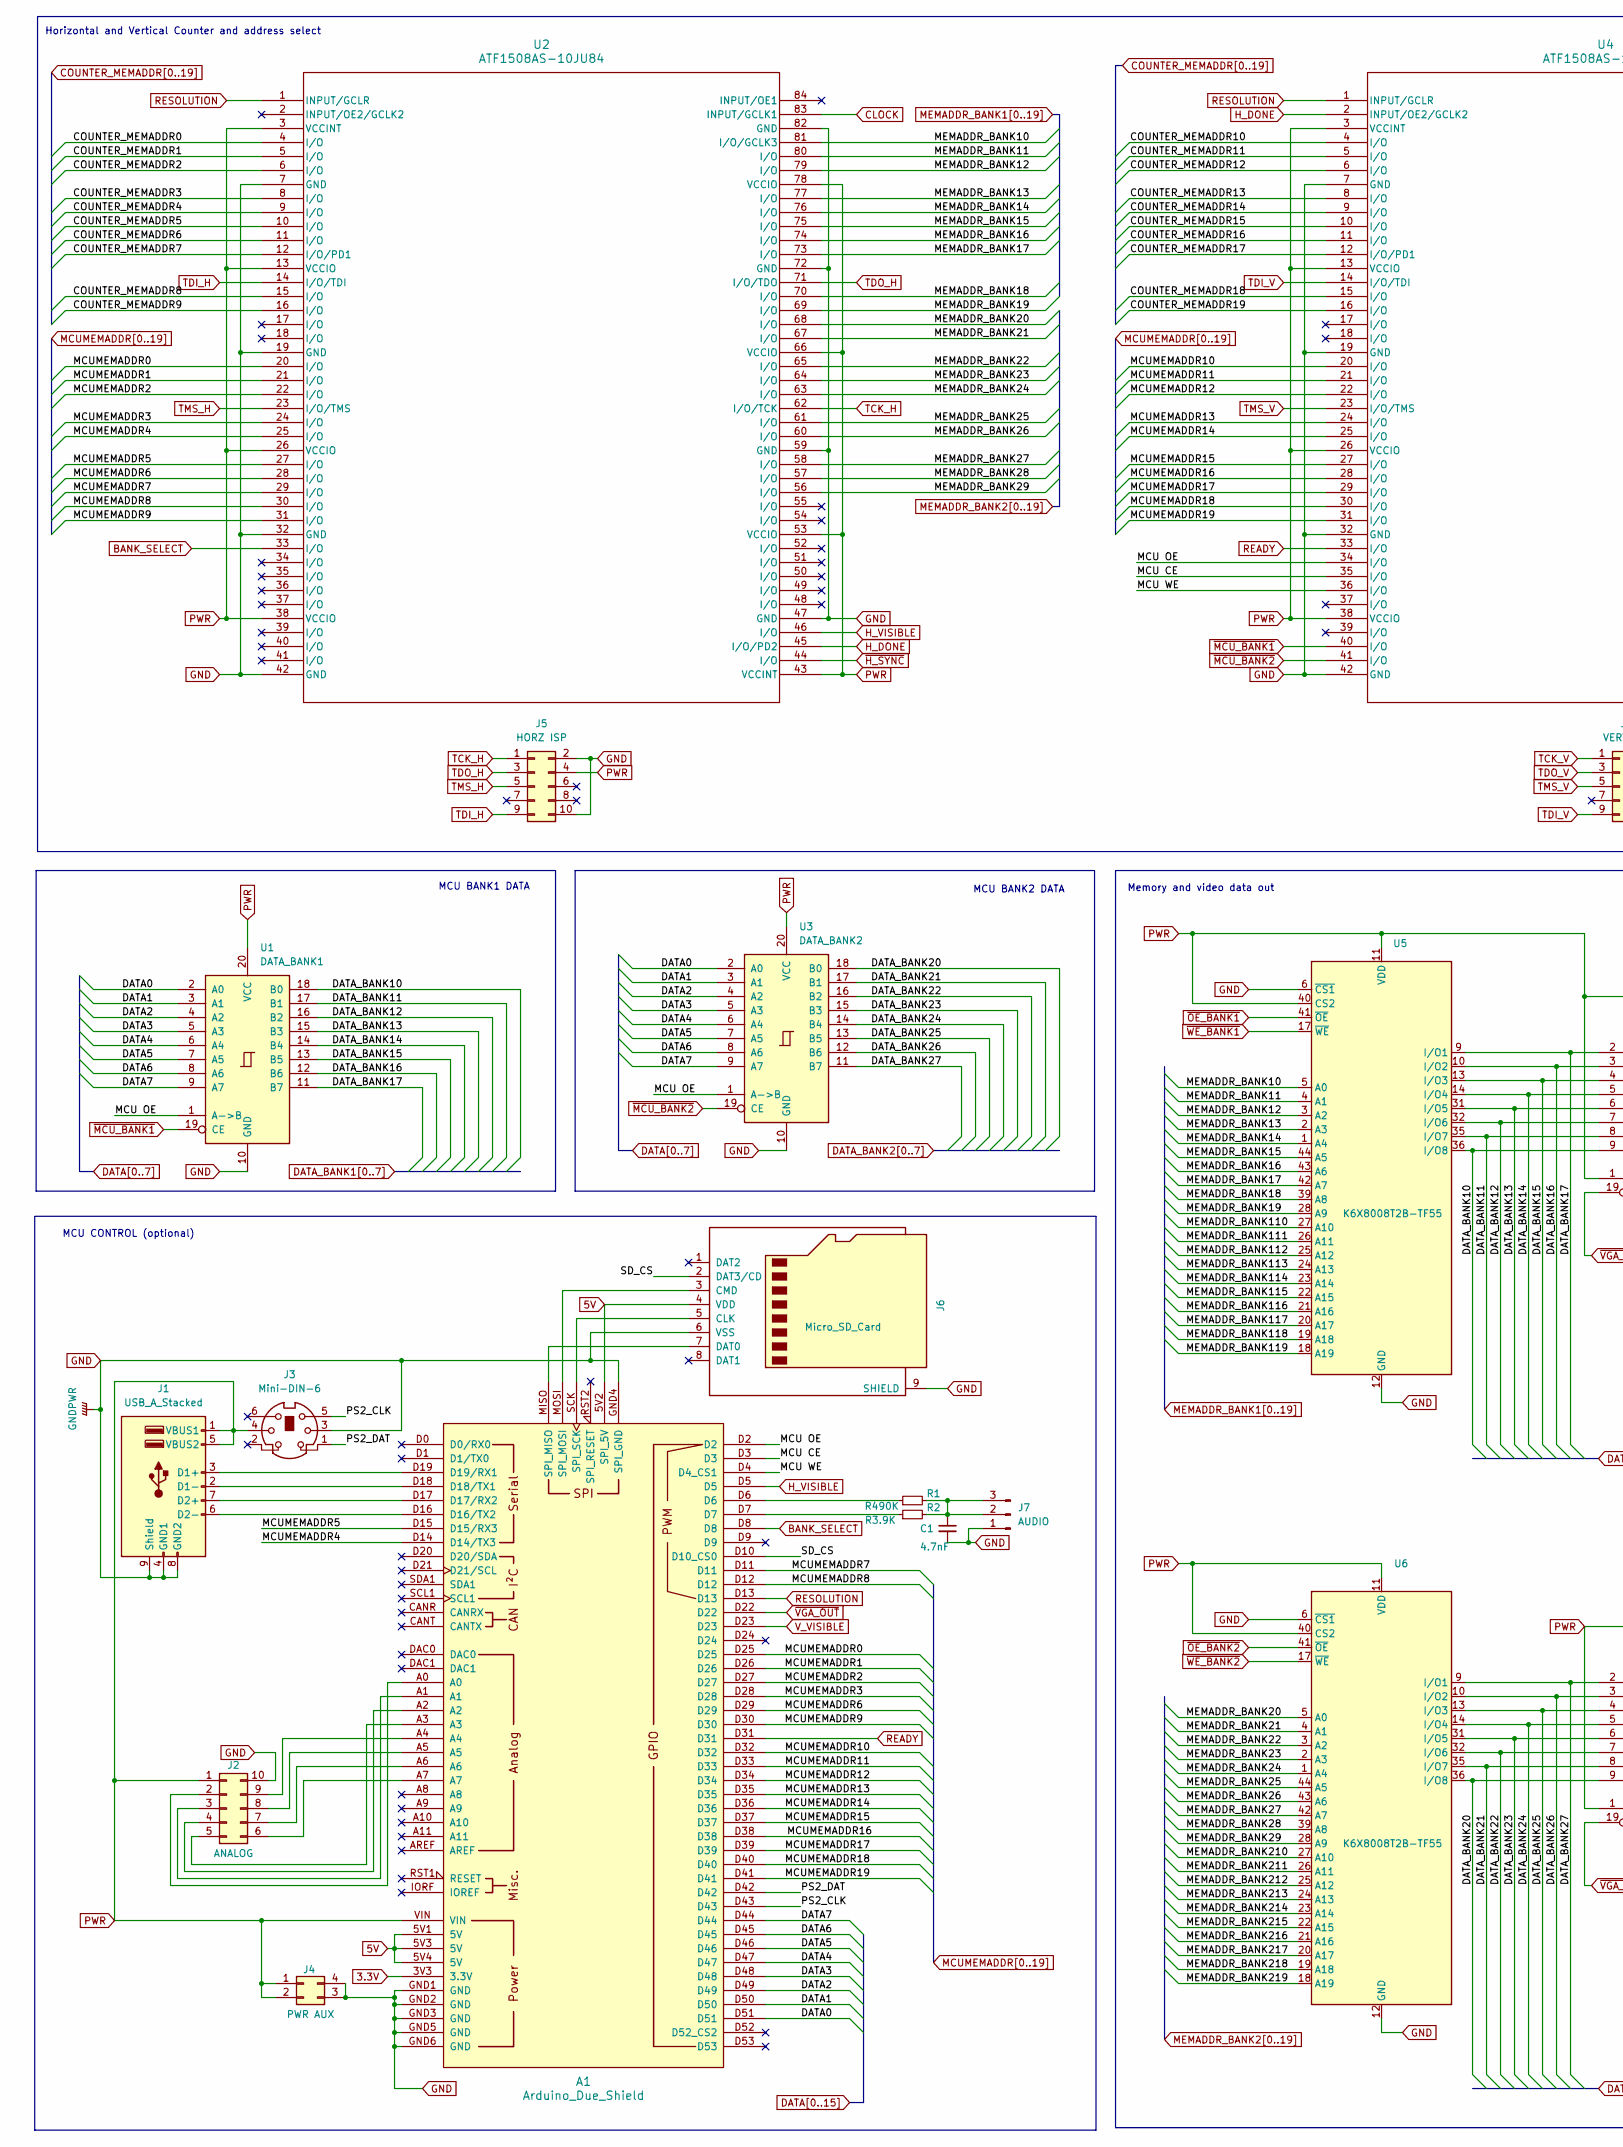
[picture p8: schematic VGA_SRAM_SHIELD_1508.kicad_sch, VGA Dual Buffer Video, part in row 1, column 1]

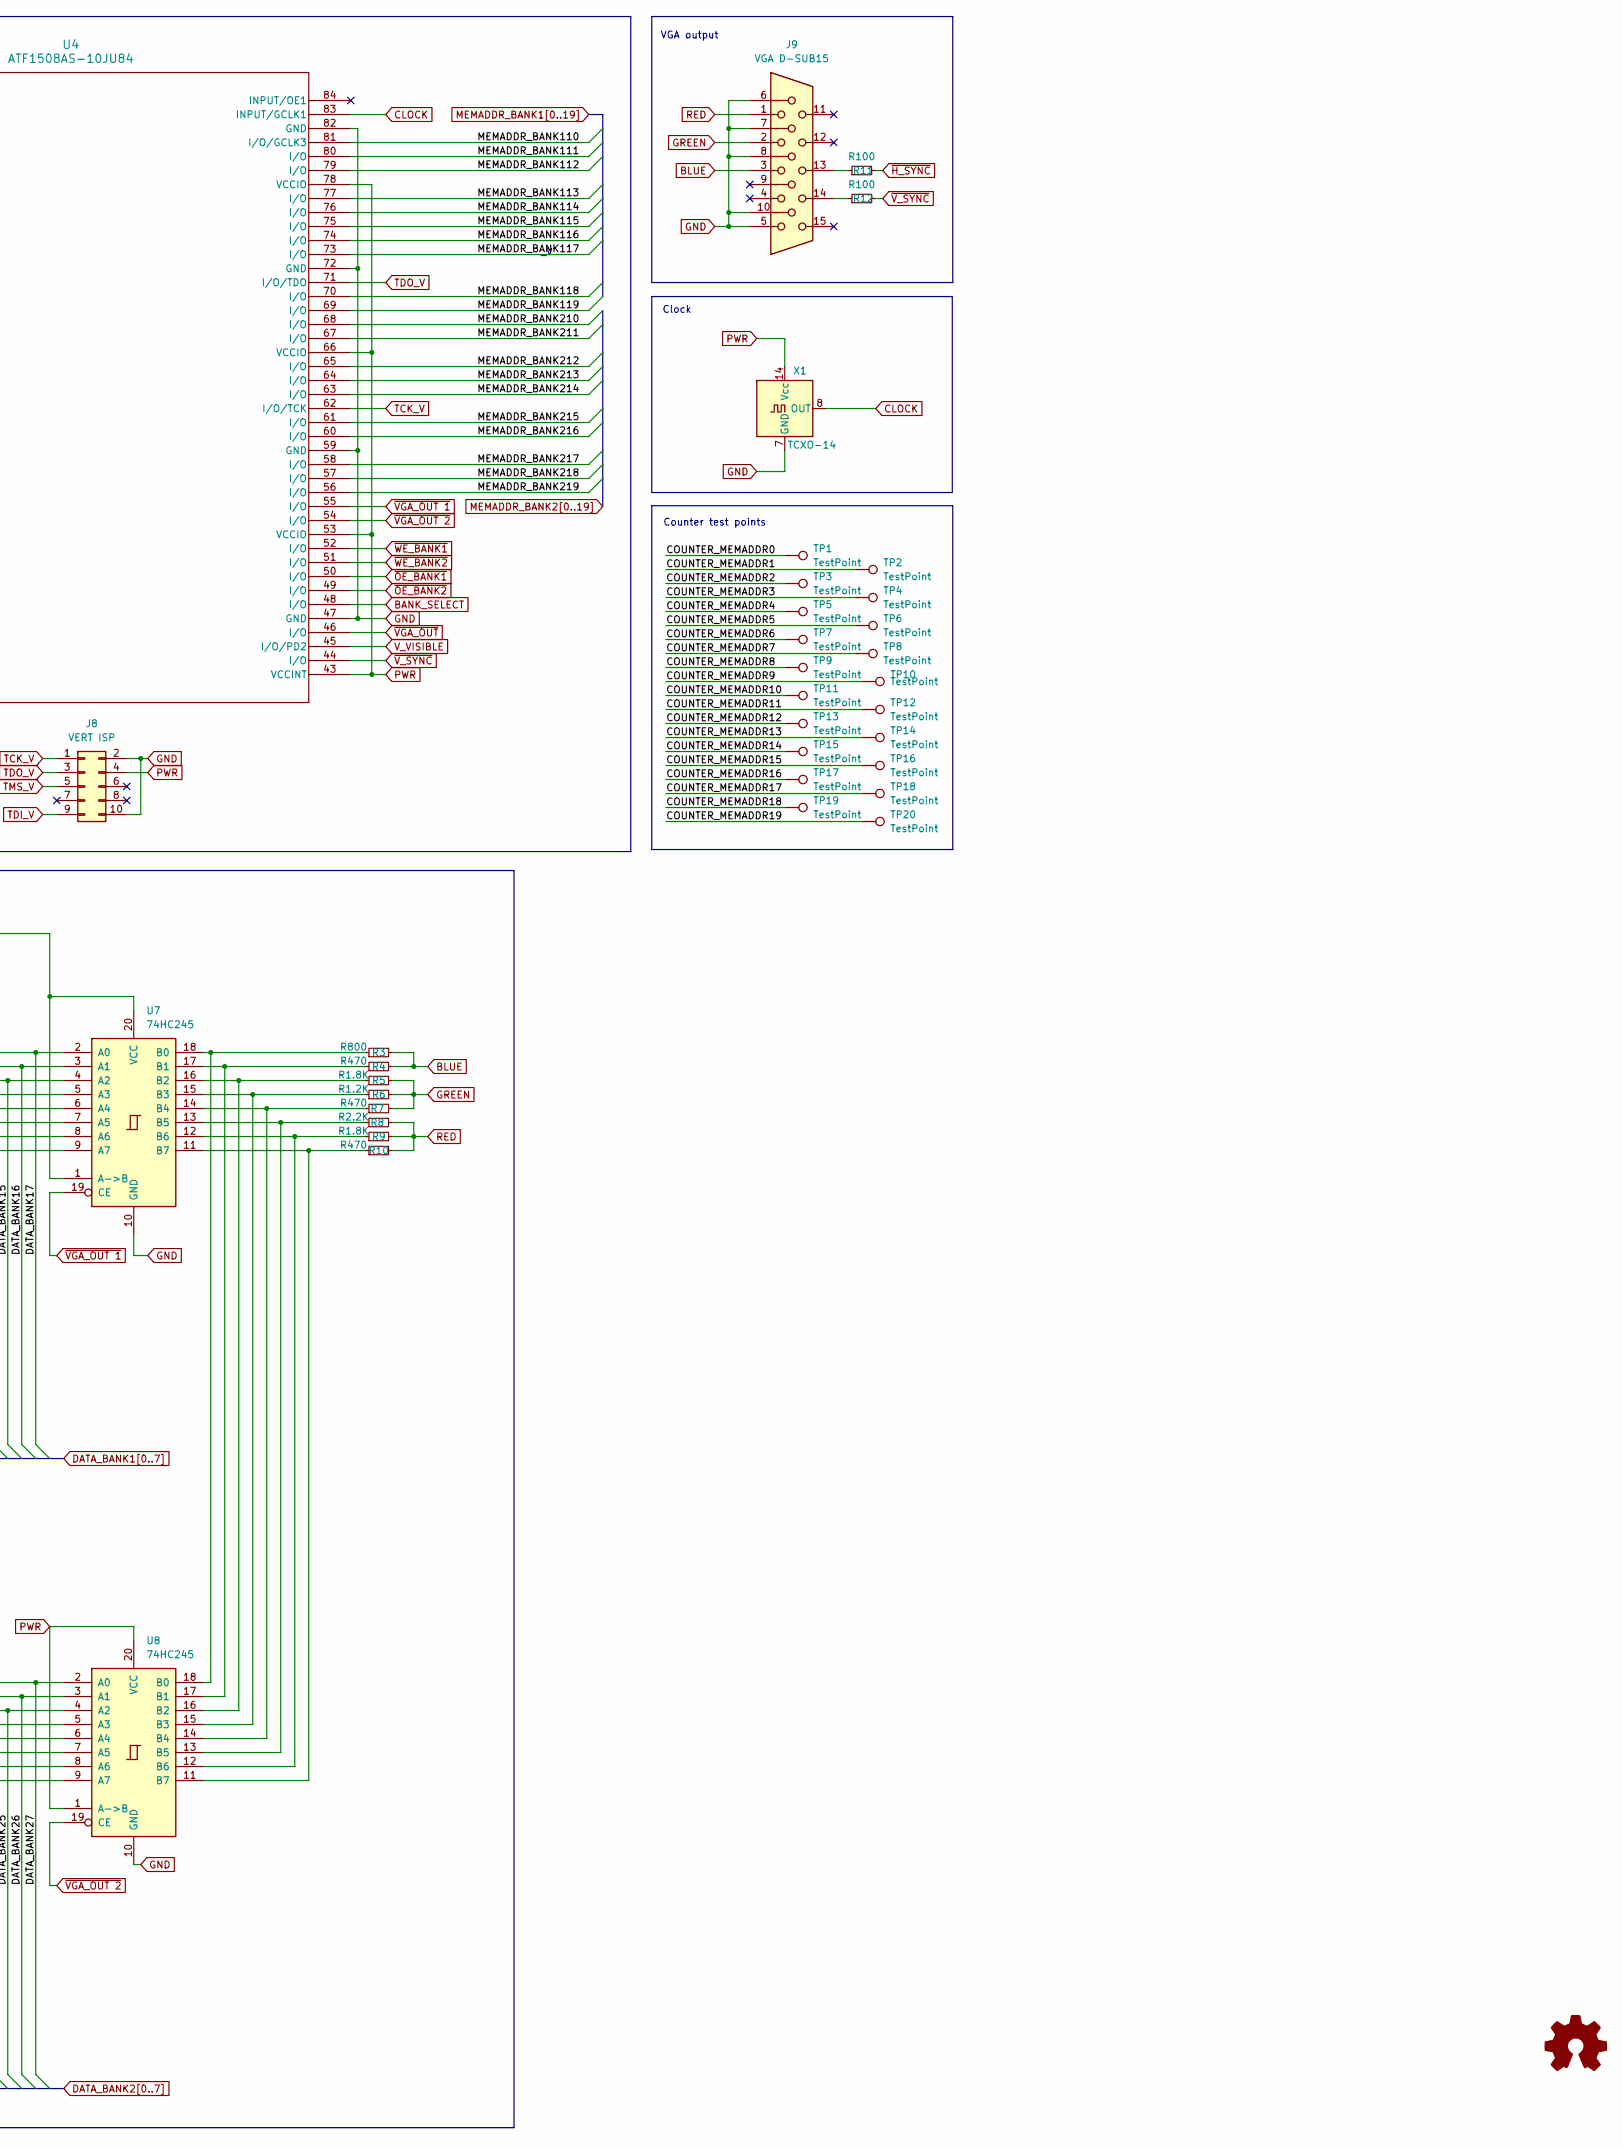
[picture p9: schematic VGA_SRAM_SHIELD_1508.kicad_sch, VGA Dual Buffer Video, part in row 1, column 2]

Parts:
A1: Arduino_Due_Shield
C1: 4.7nF; C_0805_2012Metric
J1: USB_A_Stacked; USB_A_CUI_UJ2-ADH-TH_Horizontal_Stacked
J2: ANALOG; PinSocket_2x05_P2.54mm_Vertical
J3: Mini-DIN-6; mini-DIN 6
J4: PWR AUX; PinSocket_2x02_P2.54mm_Vertical
J5: HORZ ISP; PinSocket_2x05_P2.54mm_Vertical
J6: Micro_SD_Card; J_SD_Card-micro_socket_A
J7: AUDIO; PinSocket_1x03_P2.54mm_Vertical
J8: VERT ISP; PinSocket_2x05_P2.54mm_Vertical
J9: VGA D-SUB15; DSUB-15-HD_Female_Horizontal_P2.29x1.90mm_EdgePinOffset3.03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
R1: R490K; R_0805_2012Metric
R2: R3.9K; R_0805_2012Metric
R3: R800; R_0805_2012Metric
R4, R7, R10: R470; R_0805_2012Metric
R5, R9: R1.8K; R_0805_2012Metric
R6: R1.2K; R_0805_2012Metric
R8: R2.2K; R_0805_2012Metric
R11, R12: R100; R_0805_2012Metric
TP1, TP2, TP3, TP4, TP5, TP6, TP7, TP8, TP9, TP10, TP11, TP12, TP13, TP14, TP15, TP16, TP17, TP18, TP19, TP20: TestPoint; TestPoint_Pad_D1.0mm
U1: DATA_BANK1; SOP-20_7.5x12.8mm_P1.27mm
U2, U4: ATF1508AS-10JU84; PLCC84AT
U3: DATA_BANK2; SOP-20_7.5x12.8mm_P1.27mm
U5, U6: K6X8008T2B-TF55; TSOP-II-44_10.16x18.41mm_P0.8mm
U7, U8: 74HC245; SOP-20_7.5x12.8mm_P1.27mm
X1: TCXO-14; Oscillator_DIP-14

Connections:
3.3V: A1.3V3 (3.3V)
5V: A1.5V1 (5V), A1.5V2 (SPI_5V), A1.5V3 (5V), A1.5V4 (5V), J6.4 (VDD)
/MCU CE: A1.D3, U4.35 (I/O)
/MCU OE: A1.D2, U1.1 (A->B), U3.1 (A->B), U4.34 (I/O)
/MCU WE: A1.D4 (D4_CS1), U4.36 (I/O)
/PS2_CLK: A1.D43, J3.5
/PS2_DAT: A1.D42, J3.1
/SD_CS: A1.D10 (D10_CS0), J6.2 (DAT3/CD)
BANK_SELECT: A1.D8, U2.33 (I/O), U4.48 (I/O)
BLUE: J9.3, R3.2, R4.2
CLOCK: U2.83 (INPUT/GCLK1), U4.83 (INPUT/GCLK1), X1.8 (OUT)
COUNTER_MEMADDR0: TP1.1, U2.4 (I/O)
COUNTER_MEMADDR1: TP2.1, U2.5 (I/O)
COUNTER_MEMADDR2: TP3.1, U2.6 (I/O)
COUNTER_MEMADDR3: TP4.1, U2.8 (I/O)
COUNTER_MEMADDR4: TP5.1, U2.9 (I/O)
COUNTER_MEMADDR5: TP6.1, U2.10 (I/O)
COUNTER_MEMADDR6: TP7.1, U2.11 (I/O)
COUNTER_MEMADDR7: TP8.1, U2.12 (I/O/PD1)
COUNTER_MEMADDR8: TP9.1, U2.15 (I/O)
COUNTER_MEMADDR9: TP10.1, U2.16 (I/O)
COUNTER_MEMADDR10: TP11.1, U4.4 (I/O)
COUNTER_MEMADDR11: TP12.1, U4.5 (I/O)
COUNTER_MEMADDR12: TP13.1, U4.6 (I/O)
COUNTER_MEMADDR13: TP14.1, U4.8 (I/O)
COUNTER_MEMADDR14: TP15.1, U4.9 (I/O)
COUNTER_MEMADDR15: TP16.1, U4.10 (I/O)
COUNTER_MEMADDR16: TP17.1, U4.11 (I/O)
COUNTER_MEMADDR17: TP18.1, U4.12 (I/O/PD1)
COUNTER_MEMADDR18: TP19.1, U4.15 (I/O)
COUNTER_MEMADDR19: TP20.1, U4.16 (I/O)
DATA0: A1.D51, U1.2 (A0), U3.2 (A0)
DATA1: A1.D50, U1.3 (A1), U3.3 (A1)
DATA2: A1.D49, U1.4 (A2), U3.4 (A2)
DATA3: A1.D48, U1.5 (A3), U3.5 (A3)
DATA4: A1.D47, U1.6 (A4), U3.6 (A4)
DATA5: A1.D46, U1.7 (A5), U3.7 (A5)
DATA6: A1.D45, U1.8 (A6), U3.8 (A6)
DATA7: A1.D44, U1.9 (A7), U3.9 (A7)
DATA_BANK10: U1.18 (B0), U5.36 (I/O8), U7.9 (A7)
DATA_BANK11: U1.17 (B1), U5.35 (I/O7), U7.8 (A6)
DATA_BANK12: U1.16 (B2), U5.32 (I/O6), U7.7 (A5)
DATA_BANK13: U1.15 (B3), U5.31 (I/O5), U7.6 (A4)
DATA_BANK14: U1.14 (B4), U5.14 (I/O4), U7.5 (A3)
DATA_BANK15: U1.13 (B5), U5.13 (I/O3), U7.4 (A2)
DATA_BANK16: U1.12 (B6), U5.10 (I/O2), U7.3 (A1)
DATA_BANK17: U1.11 (B7), U5.9 (I/O1), U7.2 (A0)
DATA_BANK20: U3.18 (B0), U6.36 (I/O8), U8.9 (A7)
DATA_BANK21: U3.17 (B1), U6.35 (I/O7), U8.8 (A6)
DATA_BANK22: U3.16 (B2), U6.32 (I/O6), U8.7 (A5)
DATA_BANK23: U3.15 (B3), U6.31 (I/O5), U8.6 (A4)
DATA_BANK24: U3.14 (B4), U6.14 (I/O4), U8.5 (A3)
DATA_BANK25: U3.13 (B5), U6.13 (I/O3), U8.4 (A2)
DATA_BANK26: U3.12 (B6), U6.10 (I/O2), U8.3 (A1)
DATA_BANK27: U3.11 (B7), U6.9 (I/O1), U8.2 (A0)
GND: A1.GND1 (GND), A1.GND2 (GND), A1.GND3 (GND), A1.GND4 (SPI_GND), A1.GND5 (GND), A1.GND6 (GND), C1.2, J1.4 (GND1), J1.8 (GND2), J1.9 (Shield), J2.10, J3.3, J4.3, J4.4, J5.2, J5.10, J6.6 (VSS), J6.9 (SHIELD), J7.1, J8.2, J8.10, J9.5, J9.6, J9.7, J9.8, J9.10, U1.10 (GND), U2.7 (GND), U2.19 (GND), U2.32 (GND), U2.42 (GND), U2.47 (GND), U2.59 (GND), U2.72 (GND), U2.82 (GND), U3.10 (GND), U4.7 (GND), U4.19 (GND), U4.32 (GND), U4.42 (GND), U4.47 (GND), U4.59 (GND), U4.72 (GND), U4.82 (GND), U5.6 (~CS1), U5.12 (GND), U5.34 (GND), U6.6 (~CS1), U6.12 (GND), U6.34 (GND), U7.10 (GND), U8.10 (GND), X1.7 (GND)
GREEN: J9.2, R5.2, R6.2, R7.2
H_DONE: U2.45 (I/O/PD2), U4.2 (INPUT/OE2/GCLK2)
H_VISIBLE: A1.D5, U2.46 (I/O)
MCUMEMADDR0: A1.D25, U2.20 (I/O)
MCUMEMADDR1: A1.D26, U2.21 (I/O)
MCUMEMADDR2: A1.D27, U2.22 (I/O)
MCUMEMADDR3: A1.D28, U2.24 (I/O)
MCUMEMADDR4: A1.D14 (D14/TX3), U2.25 (I/O)
MCUMEMADDR5: A1.D15 (D15/RX3), U2.27 (I/O)
MCUMEMADDR6: A1.D29, U2.28 (I/O)
MCUMEMADDR7: A1.D11, U2.29 (I/O)
MCUMEMADDR8: A1.D12, U2.30 (I/O)
MCUMEMADDR9: A1.D30, U2.31 (I/O)
MCUMEMADDR10: A1.D32, U4.20 (I/O)
MCUMEMADDR11: A1.D33, U4.21 (I/O)
MCUMEMADDR12: A1.D34, U4.22 (I/O)
MCUMEMADDR13: A1.D35, U4.24 (I/O)
MCUMEMADDR14: A1.D36, U4.25 (I/O)
MCUMEMADDR15: A1.D37, U4.27 (I/O)
MCUMEMADDR16: A1.D38, U4.28 (I/O)
MCUMEMADDR17: A1.D39, U4.29 (I/O)
MCUMEMADDR18: A1.D40, U4.30 (I/O)
MCUMEMADDR19: A1.D41, U4.31 (I/O)
MEMADDR_BANK10: U2.81 (I/O/GCLK3), U5.5 (A0)
MEMADDR_BANK11: U2.80 (I/O), U5.4 (A1)
MEMADDR_BANK12: U2.79 (I/O), U5.3 (A2)
MEMADDR_BANK13: U2.77 (I/O), U5.2 (A3)
MEMADDR_BANK14: U2.76 (I/O), U5.1 (A4)
MEMADDR_BANK15: U2.75 (I/O), U5.44 (A5)
MEMADDR_BANK16: U2.74 (I/O), U5.43 (A6)
MEMADDR_BANK17: U2.73 (I/O), U5.42 (A7)
MEMADDR_BANK18: U2.70 (I/O), U5.39 (A8)
MEMADDR_BANK19: U2.69 (I/O), U5.28 (A9)
MEMADDR_BANK20: U2.68 (I/O), U6.5 (A0)
MEMADDR_BANK21: U2.67 (I/O), U6.4 (A1)
MEMADDR_BANK22: U2.65 (I/O), U6.3 (A2)
MEMADDR_BANK23: U2.64 (I/O), U6.2 (A3)
MEMADDR_BANK24: U2.63 (I/O), U6.1 (A4)
MEMADDR_BANK25: U2.61 (I/O), U6.44 (A5)
MEMADDR_BANK26: U2.60 (I/O), U6.43 (A6)
MEMADDR_BANK27: U2.58 (I/O), U6.42 (A7)
MEMADDR_BANK28: U2.57 (I/O), U6.39 (A8)
MEMADDR_BANK29: U2.56 (I/O), U6.28 (A9)
MEMADDR_BANK110: U4.81 (I/O/GCLK3), U5.27 (A10)
MEMADDR_BANK111: U4.80 (I/O), U5.26 (A11)
MEMADDR_BANK112: U4.79 (I/O), U5.25 (A12)
MEMADDR_BANK113: U4.77 (I/O), U5.24 (A13)
MEMADDR_BANK114: U4.76 (I/O), U5.23 (A14)
MEMADDR_BANK115: U4.75 (I/O), U5.22 (A15)
MEMADDR_BANK116: U4.74 (I/O), U5.21 (A16)
MEMADDR_BANK117: U4.73 (I/O), U5.20 (A17)
MEMADDR_BANK118: U4.70 (I/O), U5.19 (A18)
MEMADDR_BANK119: U4.69 (I/O), U5.18 (A19)
MEMADDR_BANK210: U4.68 (I/O), U6.27 (A10)
MEMADDR_BANK211: U4.67 (I/O), U6.26 (A11)
MEMADDR_BANK212: U4.65 (I/O), U6.25 (A12)
MEMADDR_BANK213: U4.64 (I/O), U6.24 (A13)
MEMADDR_BANK214: U4.63 (I/O), U6.23 (A14)
MEMADDR_BANK215: U4.61 (I/O), U6.22 (A15)
MEMADDR_BANK216: U4.60 (I/O), U6.21 (A16)
MEMADDR_BANK217: U4.58 (I/O), U6.20 (A17)
MEMADDR_BANK218: U4.57 (I/O), U6.19 (A18)
MEMADDR_BANK219: U4.56 (I/O), U6.18 (A19)
unnamed: A1.D16 (D16/TX2), J1.6 (D2-)
unnamed: A1.D17 (D17/RX2), J1.7 (D2+)
unnamed: A1.D18 (D18/TX1), J1.2 (D1-)
unnamed: A1.D19 (D19/RX1), J1.3 (D1+)
unnamed: A1.D6, R1.1
unnamed: A1.D7, R2.1
unnamed: A1.MISO (SPI_MISO), J6.7 (DAT0)
unnamed: A1.MOSI (SPI_MOSI), J6.3 (CMD)
unnamed: A1.SCK (SPI_SCK), J6.5 (CLK)
unnamed: A1.A0, J2.2
unnamed: A1.A1, J2.3
unnamed: A1.A2, J2.4
unnamed: A1.A3, J2.5
unnamed: A1.A7, J2.6
unnamed: A1.A6, J2.7
unnamed: A1.A5, J2.8
unnamed: A1.A4, J2.9
unnamed: C1.1, J7.2, J7.3, R1.2, R2.2
unnamed: J9.13, R11.1
unnamed: J9.14, R12.1
unnamed: R3.1, U7.18 (B0), U8.18 (B0)
unnamed: R4.1, U7.17 (B1), U8.17 (B1)
unnamed: R5.1, U7.16 (B2), U8.16 (B2)
unnamed: R6.1, U7.15 (B3), U8.15 (B3)
unnamed: R7.1, U7.14 (B4), U8.14 (B4)
unnamed: R8.1, U7.13 (B5), U8.13 (B5)
unnamed: R9.1, U7.12 (B6), U8.12 (B6)
unnamed: R10.1, U7.11 (B7), U8.11 (B7)
PWR: A1.VIN, J1.1 (VBUS1), J1.5 (VBUS2), J2.1, J3.4, J4.1, J4.2, J5.4, J8.4, U1.20 (VCC), U2.3 (VCCINT), U2.13 (VCCIO), U2.26 (VCCIO), U2.38 (VCCIO), U2.43 (VCCINT), U2.53 (VCCIO), U2.66 (VCCIO), U2.78 (VCCIO), U3.20 (VCC), U4.3 (VCCINT), U4.13 (VCCIO), U4.26 (VCCIO), U4.38 (VCCIO), U4.43 (VCCINT), U4.53 (VCCIO), U4.66 (VCCIO), U4.78 (VCCIO), U5.11 (VDD), U5.33 (VDD), U5.40 (CS2), U6.11 (VDD), U6.33 (VDD), U6.40 (CS2), U7.1 (A->B), U7.20 (VCC), U8.1 (A->B), U8.20 (VCC), X1.14 (Vcc)
READY: A1.D31, U4.33 (I/O)
RED: J9.1, R8.2, R9.2, R10.2
RESOLUTION: A1.D13, U2.1 (INPUT/GCLR), U4.1 (INPUT/GCLR)
TCK_H: J5.1, U2.62 (I/O/TCK)
TCK_V: J8.1, U4.62 (I/O/TCK)
TDI_H: J5.9, U2.14 (I/O/TDI)
TDI_V: J8.9, U4.14 (I/O/TDI)
TDO_H: J5.3, U2.71 (I/O/TDO)
TDO_V: J8.3, U4.71 (I/O/TDO)
TMS_H: J5.5, U2.23 (I/O/TMS)
TMS_V: J8.5, U4.23 (I/O/TMS)
V_VISIBLE: A1.D23, U4.45 (I/O/PD2)
~H_SYNC: R11.2, U2.44 (I/O)
~MCU_BANK1: U1.19 (CE), U4.40 (I/O)
~MCU_BANK2: U3.19 (CE), U4.41 (I/O)
~OE_BANK1: U4.50 (I/O), U5.41 (~OE)
~OE_BANK2: U4.49 (I/O), U6.41 (~OE)
~VGA_OUT 1: U4.55 (I/O), U7.19 (CE)
~VGA_OUT 2: U4.54 (I/O), U8.19 (CE)
~VGA_OUT: A1.D22, U4.46 (I/O)
~V_SYNC: R12.2, U4.44 (I/O)
~WE_BANK1: U4.52 (I/O), U5.17 (~WE)
~WE_BANK2: U4.51 (I/O), U6.17 (~WE)

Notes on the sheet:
Horizontal and Vertical Counter and address select
Memory and video data out
Clock
Counter test points
MCU BANK1 DATA
MCU BANK2 DATA
MCU CONTROL (optional)
VGA output

Board: 4 copper layers, 52 parts (4 on the bottom side), 170 nets, no tracks yet.

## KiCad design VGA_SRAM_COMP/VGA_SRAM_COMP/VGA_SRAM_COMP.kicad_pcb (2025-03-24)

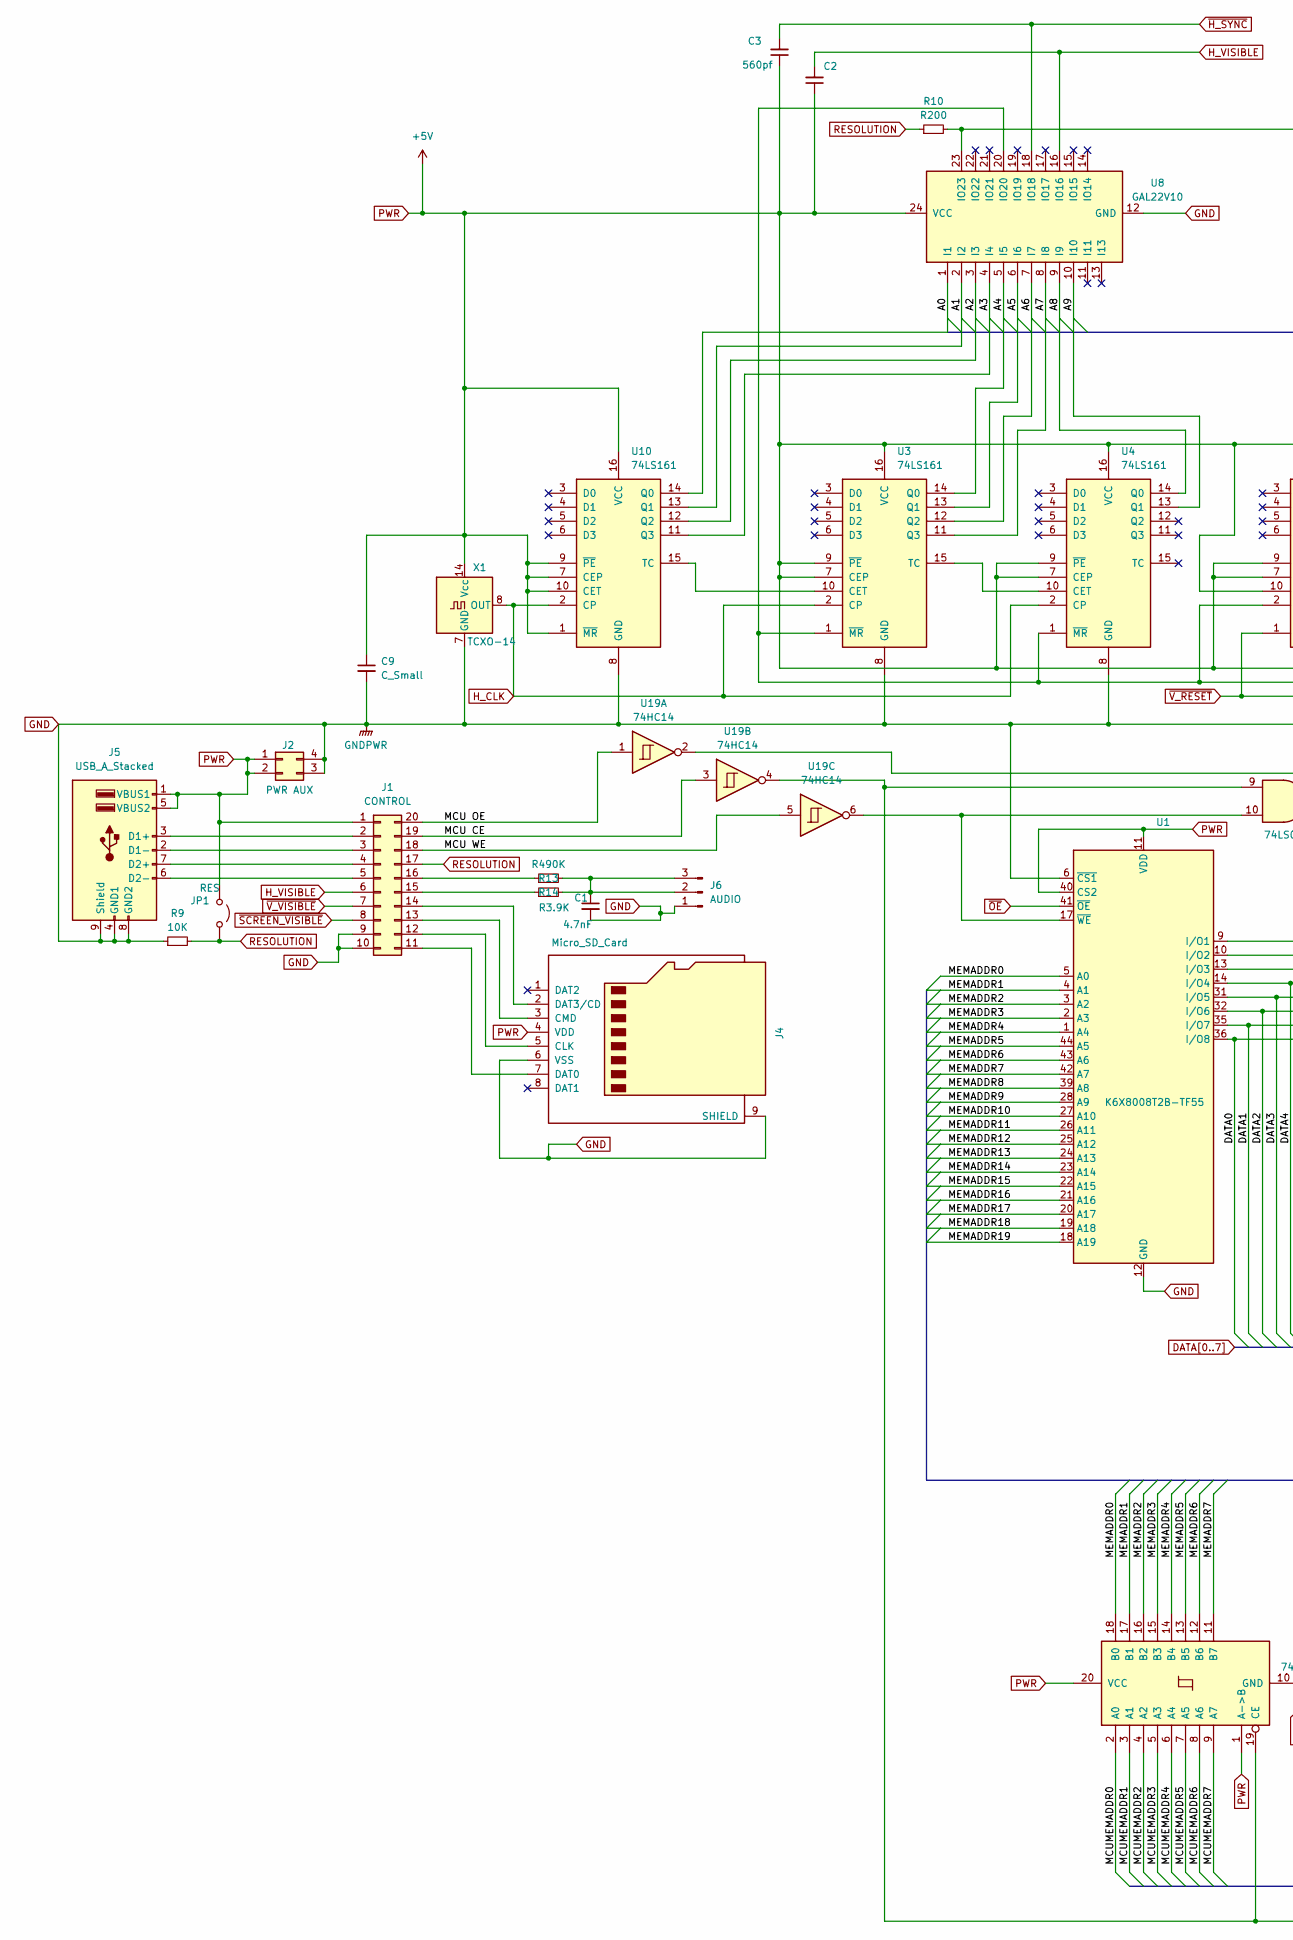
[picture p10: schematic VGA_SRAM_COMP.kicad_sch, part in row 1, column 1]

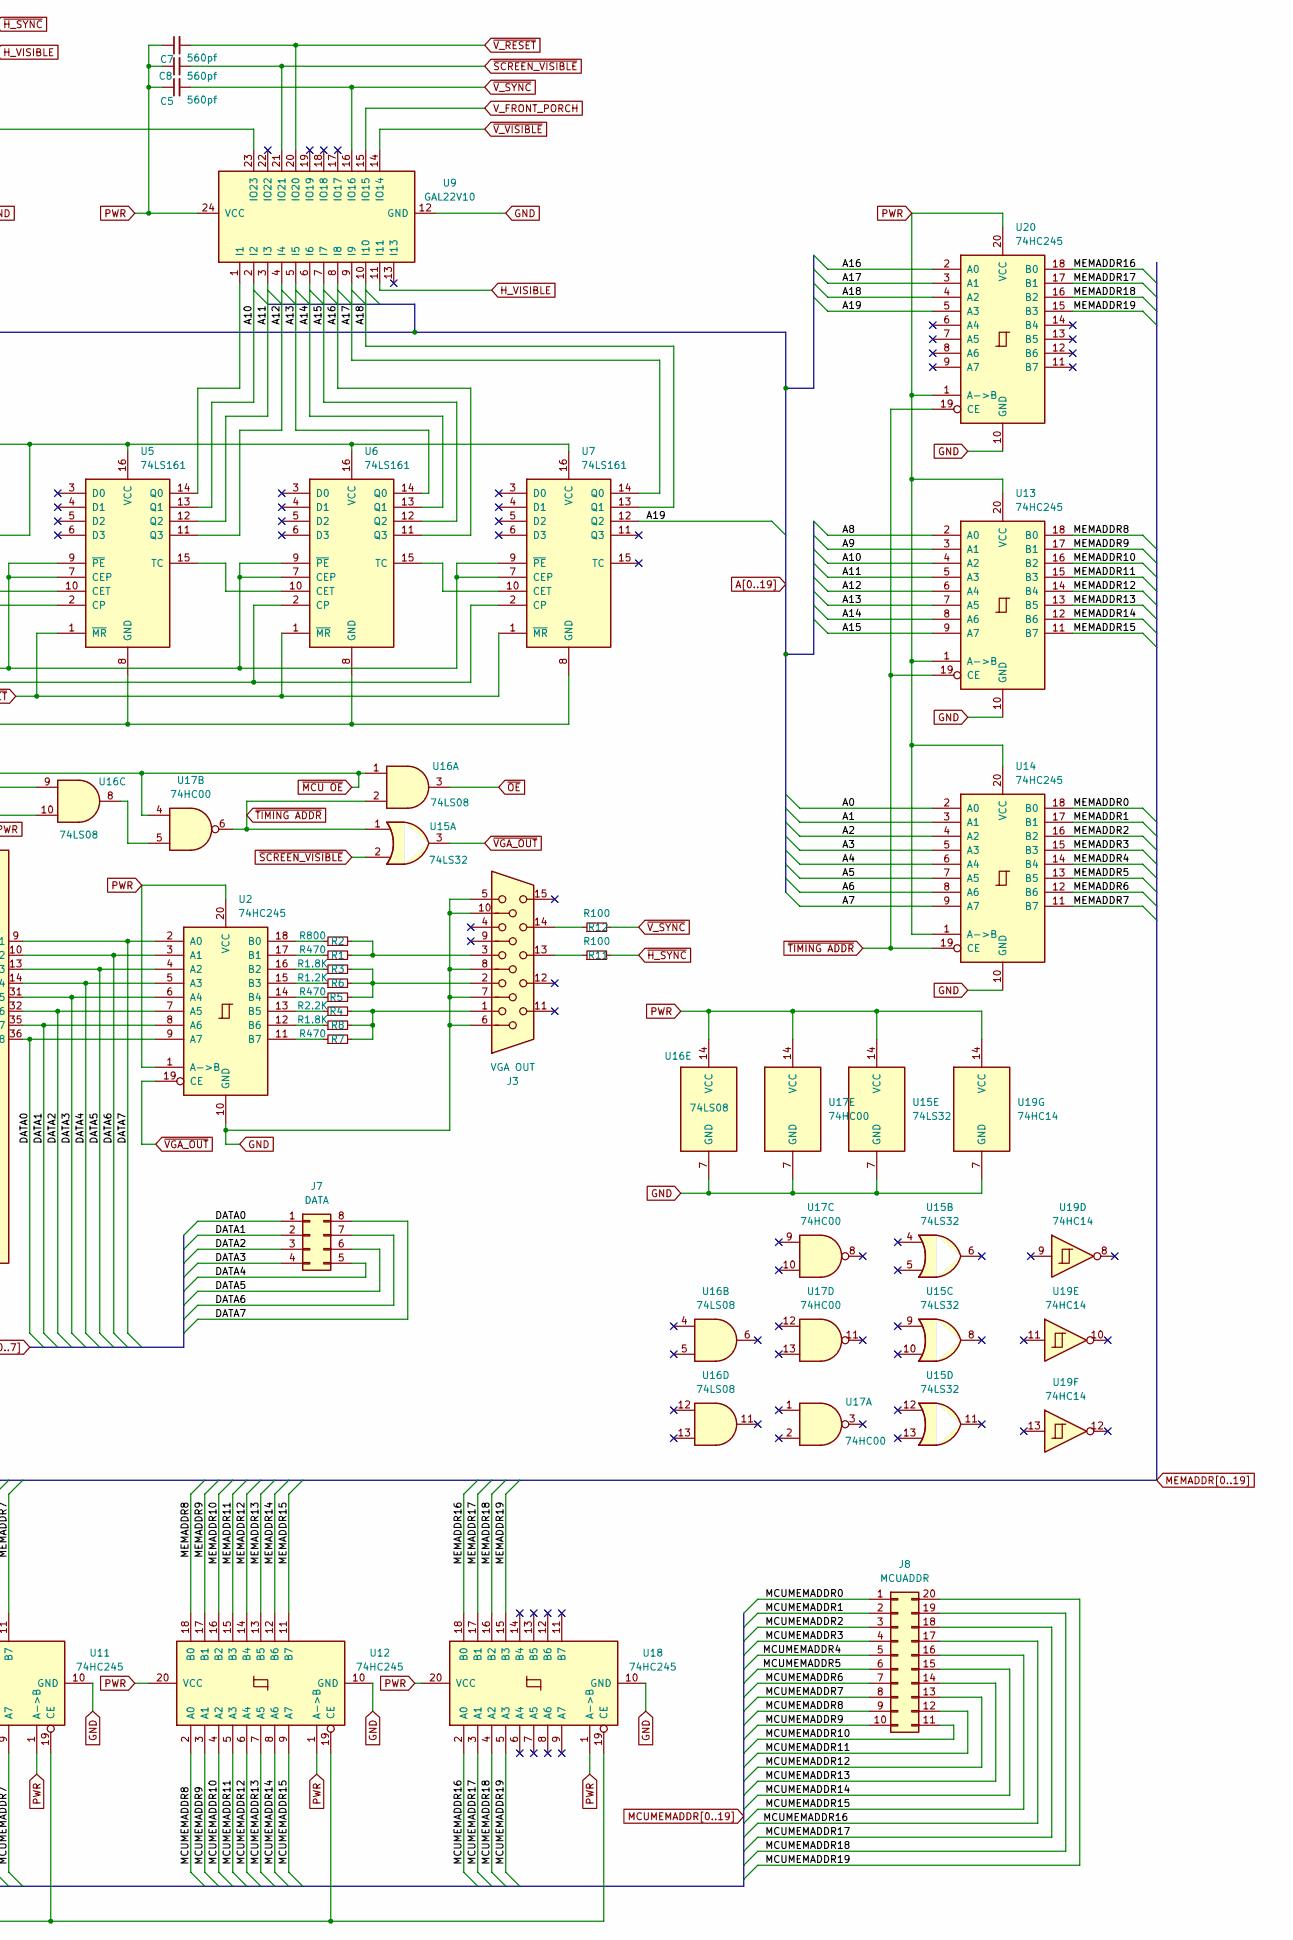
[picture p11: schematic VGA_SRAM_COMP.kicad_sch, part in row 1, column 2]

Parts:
C1: 4.7nF; C_0805_2012Metric
C2, C3, C5, C7, C8: 560pf; C_0805_2012Metric
C9: C_Small; CP_Elec_4x4.5
J1: CONTROL; PinHeader_2x10_P2.54mm_Horizontal
J2: PWR AUX; PinSocket_2x02_P2.54mm_Vertical
J3: VGA OUT; DSUB-15-HD_Female_Horizontal_P2.29x1.98mm_EdgePinOffset8.35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
J4: Micro_SD_Card; J_SD_Card-micro_socket_A
J5: USB_A_Stacked; USB_A_CUI_UJ2-ADH-TH_Horizontal_Stacked
J6: AUDIO; PinSocket_1x03_P2.54mm_Vertical
J7: DATA; PinHeader_2x04_P2.54mm_Horizontal
J8: MCUADDR; PinHeader_2x10_P2.54mm_Horizontal
JP1: RES; PinHeader_1x02_P2.54mm_Vertical
R1, R5, R7: R470; R_0805_2012Metric
R2: R800; R_0805_2012Metric
R3, R8: R1.8K; R_0805_2012Metric
R4: R2.2K; R_0805_2012Metric
R6: R1.2K; R_0805_2012Metric
R9: 10K; R_0805_2012Metric
R10: R200; R_0805_2012Metric
R11, R12: R100; R_0805_2012Metric
R13: R490K; R_0805_2012Metric
R14: R3.9K; R_0805_2012Metric
U1: K6X8008T2B-TF55; TSOP-II-44_10.16x18.41mm_P0.8mm
U2, U11, U12, U13, U14, U18, U20: 74HC245; SOP-20_7.5x12.8mm_P1.27mm
U3, U4, U5, U6, U7, U10: 74LS161; SO-16_3.9x9.9mm_P1.27mm
U8, U9: GAL22V10; DIP-24_W7.62mm_Socket
U15: 74LS32; SO-14_3.9x8.65mm_P1.27mm
U16: 74LS08; SO-14_3.9x8.65mm_P1.27mm
U17: 74HC00; SO-14_3.9x8.65mm_P1.27mm
U19: 74HC14; SO-14_3.9x8.65mm_P1.27mm
X1: TCXO-14; Oscillator_DIP-14

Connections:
/MCU CE: J1.19, U19.3
/MCU OE: J1.20, U19.1
/MCU WE: J1.18, U19.5
A0: U8.1 (I1), U10.14 (Q0), U14.2 (A0)
A1: U8.2 (I2), U10.13 (Q1), U14.3 (A1)
A2: U8.3 (I3), U10.12 (Q2), U14.4 (A2)
A3: U8.4 (I4), U10.11 (Q3), U14.5 (A3)
A4: U3.14 (Q0), U8.5 (I5), U14.6 (A4)
A5: U3.13 (Q1), U8.6 (I6), U14.7 (A5)
A6: U3.12 (Q2), U8.7 (I7), U14.8 (A6)
A7: U3.11 (Q3), U8.8 (I8), U14.9 (A7)
A8: U4.14 (Q0), U8.9 (I9), U13.2 (A0)
A9: U4.13 (Q1), U8.10 (I10), U13.3 (A1)
A10: U5.13 (Q1), U9.2 (I2), U13.4 (A2)
A11: U5.12 (Q2), U9.3 (I3), U13.5 (A3)
A12: U5.11 (Q3), U9.4 (I4), U13.6 (A4)
A13: U6.14 (Q0), U9.5 (I5), U13.7 (A5)
A14: U6.13 (Q1), U9.6 (I6), U13.8 (A6)
A15: U6.12 (Q2), U9.7 (I7), U13.9 (A7)
A16: U6.11 (Q3), U9.8 (I8), U20.2 (A0)
A17: U7.14 (Q0), U9.9 (I9), U20.3 (A1)
A18: U7.13 (Q1), U9.10 (I10), U20.4 (A2)
A19: U7.12 (Q2), U20.5 (A3)
DATA0: J7.1, U1.36 (I/O8), U2.9 (A7)
DATA1: J7.2, U1.35 (I/O7), U2.8 (A6)
DATA2: J7.3, U1.32 (I/O6), U2.7 (A5)
DATA3: J7.4, U1.31 (I/O5), U2.6 (A4)
DATA4: J7.5, U1.14 (I/O4), U2.5 (A3)
DATA5: J7.6, U1.13 (I/O3), U2.4 (A2)
DATA6: J7.7, U1.10 (I/O2), U2.3 (A1)
DATA7: J7.8, U1.9 (I/O1), U2.2 (A0)
GND: C1.2, C9.2, J1.9, J1.10, J2.3, J2.4, J3.5, J3.6, J3.7, J3.8, J3.10, J4.6 (VSS), J4.9 (SHIELD), J5.4 (GND1), J5.8 (GND2), J5.9 (Shield), J6.1, R9.1, U1.6 (~CS1), U1.12 (GND), U1.34 (GND), U2.10 (GND), U3.8 (GND), U4.8 (GND), U5.8 (GND), U6.8 (GND), U7.8 (GND), U8.12 (GND), U9.12 (GND), U10.8 (GND), U11.10 (GND), U12.10 (GND), U13.10 (GND), U14.10 (GND), U15.7 (GND), U16.7 (GND), U17.7 (GND), U18.10 (GND), U19.7 (GND), U20.10 (GND), X1.7 (GND)
H_CLK: U3.2 (CP), U4.2 (CP), U10.2 (CP), X1.8 (OUT)
H_VISIBLE: C2.2, J1.6, U8.16 (IO16), U9.11 (I11)
MCUMEMADDR0: J8.1, U11.2 (A0)
MCUMEMADDR1: J8.2, U11.3 (A1)
MCUMEMADDR2: J8.3, U11.4 (A2)
MCUMEMADDR3: J8.4, U11.5 (A3)
MCUMEMADDR4: J8.5, U11.6 (A4)
MCUMEMADDR5: J8.6, U11.7 (A5)
MCUMEMADDR6: J8.7, U11.8 (A6)
MCUMEMADDR7: J8.8, U11.9 (A7)
MCUMEMADDR8: J8.9, U12.2 (A0)
MCUMEMADDR9: J8.10, U12.3 (A1)
MCUMEMADDR10: J8.11, U12.4 (A2)
MCUMEMADDR11: J8.12, U12.5 (A3)
MCUMEMADDR12: J8.13, U12.6 (A4)
MCUMEMADDR13: J8.14, U12.7 (A5)
MCUMEMADDR14: J8.15, U12.8 (A6)
MCUMEMADDR15: J8.16, U12.9 (A7)
MCUMEMADDR16: J8.17, U18.2 (A0)
MCUMEMADDR17: J8.18, U18.3 (A1)
MCUMEMADDR18: J8.19, U18.4 (A2)
MCUMEMADDR19: J8.20, U18.5 (A3)
MEMADDR0: U1.5 (A0), U11.18 (B0), U14.18 (B0)
MEMADDR1: U1.4 (A1), U11.17 (B1), U14.17 (B1)
MEMADDR2: U1.3 (A2), U11.16 (B2), U14.16 (B2)
MEMADDR3: U1.2 (A3), U11.15 (B3), U14.15 (B3)
MEMADDR4: U1.1 (A4), U11.14 (B4), U14.14 (B4)
MEMADDR5: U1.44 (A5), U11.13 (B5), U14.13 (B5)
MEMADDR6: U1.43 (A6), U11.12 (B6), U14.12 (B6)
MEMADDR7: U1.42 (A7), U11.11 (B7), U14.11 (B7)
MEMADDR8: U1.39 (A8), U12.18 (B0), U13.18 (B0)
MEMADDR9: U1.28 (A9), U12.17 (B1), U13.17 (B1)
MEMADDR10: U1.27 (A10), U12.16 (B2), U13.16 (B2)
MEMADDR11: U1.26 (A11), U12.15 (B3), U13.15 (B3)
MEMADDR12: U1.25 (A12), U12.14 (B4), U13.14 (B4)
MEMADDR13: U1.24 (A13), U12.13 (B5), U13.13 (B5)
MEMADDR14: U1.23 (A14), U12.12 (B6), U13.12 (B6)
MEMADDR15: U1.22 (A15), U12.11 (B7), U13.11 (B7)
MEMADDR16: U1.21 (A16), U18.18 (B0), U20.18 (B0)
MEMADDR17: U1.20 (A17), U18.17 (B1), U20.17 (B1)
MEMADDR18: U1.19 (A18), U18.16 (B2), U20.16 (B2)
MEMADDR19: U1.18 (A19), U18.15 (B3), U20.15 (B3)
unnamed: J1.2, J5.3 (D1+)
unnamed: J1.3, J5.2 (D1-)
unnamed: J1.4, J5.7 (D2+)
unnamed: J1.5, J5.6 (D2-)
unnamed: J1.11, J4.7 (DAT0)
unnamed: J1.12, J4.5 (CLK)
unnamed: J1.13, J4.3 (CMD)
unnamed: J1.14, J4.2 (DAT3/CD)
unnamed: J1.15, R14.1
unnamed: J1.16, R13.1
unnamed: J3.1, R4.2, R7.2, R8.2
unnamed: J3.2, R3.2, R5.2, R6.2
unnamed: J3.3, R1.2, R2.2
unnamed: J3.13, R11.1
unnamed: J3.14, R12.1
unnamed: C1.1, J6.2, J6.3, R13.2, R14.2
unnamed: U1.17 (~WE), U16.10, U19.6
unnamed: R2.1, U2.18 (B0)
unnamed: R1.1, U2.17 (B1)
unnamed: R3.1, U2.16 (B2)
unnamed: R6.1, U2.15 (B3)
unnamed: R5.1, U2.14 (B4)
unnamed: R4.1, U2.13 (B5)
unnamed: R8.1, U2.12 (B6)
unnamed: R7.1, U2.11 (B7)
unnamed: U3.15 (TC), U4.10 (CET)
unnamed: U3.1 (~MR), U4.1 (~MR), U5.2 (CP), U6.2 (CP), U7.2 (CP), U8.20 (IO20)
unnamed: U5.14 (Q0), U9.1 (I1)
unnamed: U5.15 (TC), U6.10 (CET)
unnamed: U6.15 (TC), U7.10 (CET)
unnamed: R10.2, U8.23 (IO23), U9.23 (IO23)
unnamed: U3.10 (CET), U10.15 (TC)
unnamed: U11.19 (CE), U12.19 (CE), U16.9, U18.19 (CE), U19.4
unnamed: U16.8, U17.5
PWR: C2.1, C3.1, C5.1, C7.1, C8.1, C9.1, J1.1, J2.1, J2.2, J4.4 (VDD), J5.1 (VBUS1), J5.5 (VBUS2), JP1.1 (A), U1.11 (VDD), U1.33 (VDD), U1.40 (CS2), U2.1 (A->B), U2.20 (VCC), U3.7 (CEP), U3.9 (~PE), U3.16 (VCC), U4.7 (CEP), U4.9 (~PE), U4.16 (VCC), U5.7 (CEP), U5.9 (~PE), U5.10 (CET), U5.16 (VCC), U6.7 (CEP), U6.9 (~PE), U6.16 (VCC), U7.7 (CEP), U7.9 (~PE), U7.16 (VCC), U8.24 (VCC), U9.24 (VCC), U10.1 (~MR), U10.7 (CEP), U10.9 (~PE), U10.10 (CET), U10.16 (VCC), U11.1 (A->B), U11.20 (VCC), U12.1 (A->B), U12.20 (VCC), U13.1 (A->B), U13.20 (VCC), U14.1 (A->B), U14.20 (VCC), U15.14 (VCC), U16.14 (VCC), U17.14 (VCC), U18.1 (A->B), U18.20 (VCC), U19.14 (VCC), U20.1 (A->B), U20.20 (VCC), X1.14 (Vcc)
RESOLUTION: J1.17, JP1.2 (B), R9.2, R10.1
V_FRONT_PORCH: U9.15 (IO15)
~H_SYNC: C3.2, R11.2, U8.18 (IO18)
~MCU OE: U16.1, U17.4, U19.2
~OE: U1.41 (~OE), U16.3
~SCREEN_VISIBLE: C8.2, J1.8, U9.21 (IO21), U15.2
~TIMING ADDR: U13.19 (CE), U14.19 (CE), U15.1, U16.2, U17.6, U20.19 (CE)
~VGA_OUT: U2.19 (CE), U15.3
~V_RESET: C7.2, U5.1 (~MR), U6.1 (~MR), U7.1 (~MR), U9.20 (IO20)
~V_SYNC: C5.2, R12.2, U9.16 (IO16)
~V_VISIBLE: J1.7, U9.14 (IO14)

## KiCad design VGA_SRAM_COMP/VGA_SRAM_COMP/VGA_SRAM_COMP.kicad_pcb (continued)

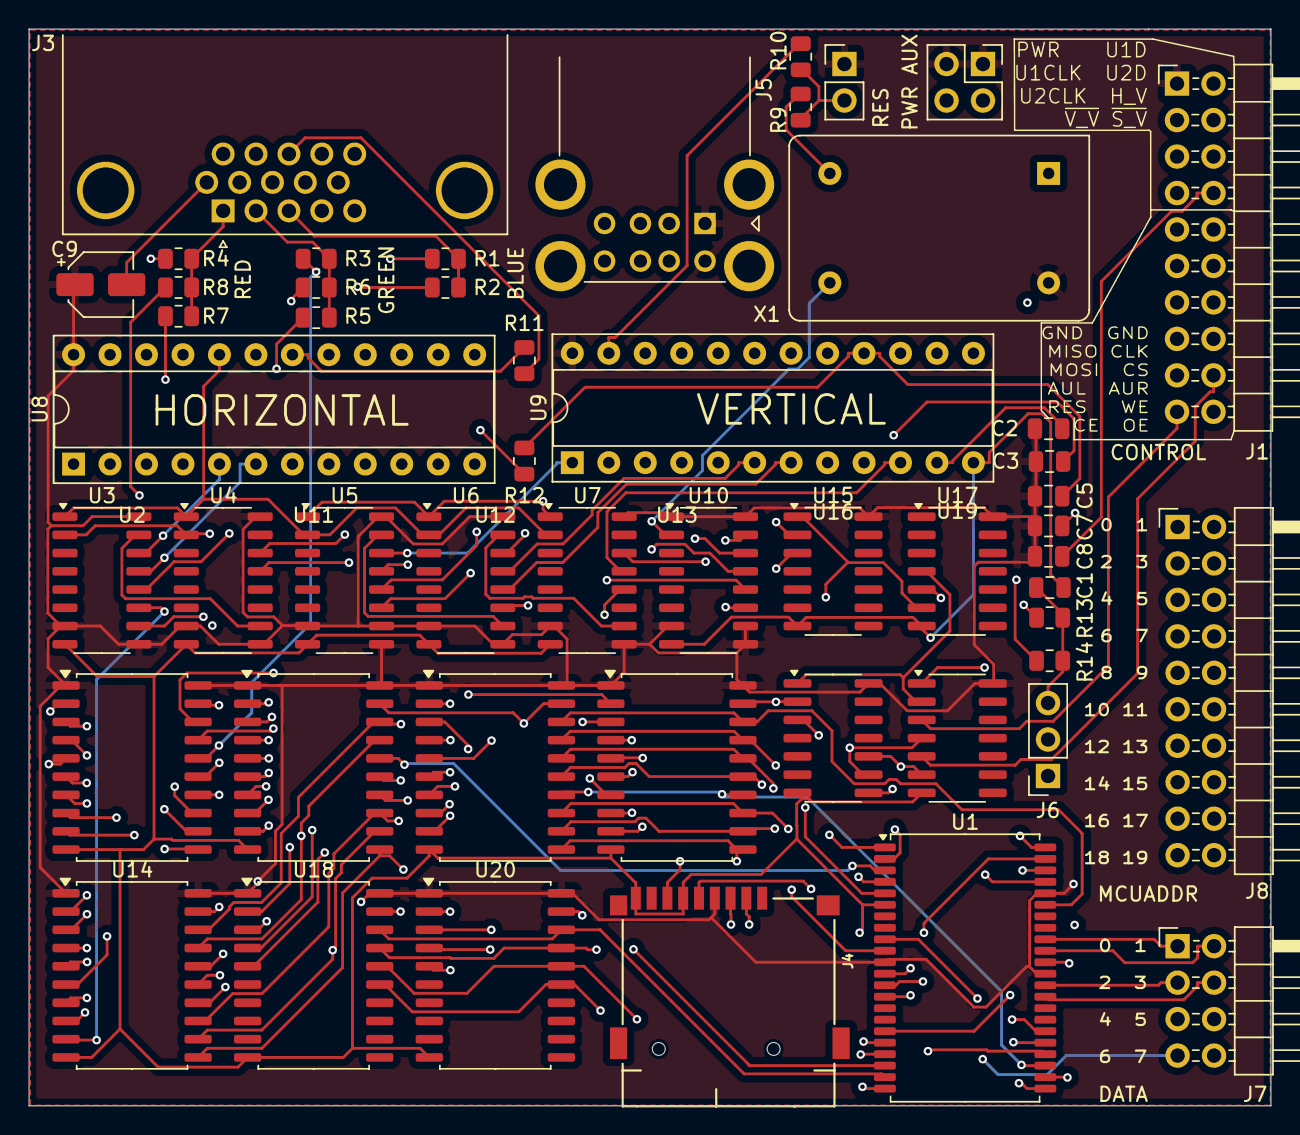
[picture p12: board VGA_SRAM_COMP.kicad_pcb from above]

Board: 4 copper layers, 86.5 x 75.0 mm, 51 parts (0 on the bottom side), 119 nets.

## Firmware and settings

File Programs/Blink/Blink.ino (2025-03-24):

// the setup function runs once when you press reset or power the board
void setup() {
  // initialize digital pin LED_BUILTIN as an output.
  pinMode(21, OUTPUT);
}

// the loop function runs over and over again forever
void loop() {
  digitalWrite(21, HIGH);   // turn the LED on (HIGH is the voltage level)
  delay(1000);                       // wait for a second
  digitalWrite(21, LOW);    // turn the LED off by making the voltage LOW
  delay(1000);                       // wait for a second
}

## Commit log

2024-11-08 add shield design, timings doc
    [VGA_SRAM_Shield.kicad_sch]
2024-11-14 added documentation. gerber of v1.0.0
    [VGA Timing.xlsx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]
2024-12-06 new shield v1.1
    [VGA_SRAM_Shield.dsn, VGA_SRAM_Shield.kicad_pcb, VGA_SRAM_Shield.kicad_sch]
2024-12-11 kicad design changes
    [VGA_SRAM_Shield.dsn, VGA_SRAM_Shield.kicad_pcb]
2025-07-16 double buffer v1
    [CHIP STATES.xlsx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]
2025-07-17 remove second vga resistor network
    [VGA_SRAM_SHUIELD_DOUBLE_BUFFER.dsn, VGA_SRAM_SHUIELD_DOUBLE_BUFFER.kicad_pcb]
2025-07-24 updates to double buffer and multiplexed, 2xatf1508 concept
    [VGA_SRAM_SHIELD_1508.dsn, VGA_SRAM_SHIELD_1508.kicad_pcb, VGA_SRAM_SHIELD_1508.kicad_sch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]
